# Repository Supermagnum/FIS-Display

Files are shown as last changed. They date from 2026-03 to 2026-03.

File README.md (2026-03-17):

# FIS-Display
VW Passat B6 FIS/MFA Display — Hardware Connections and Software Protocols.

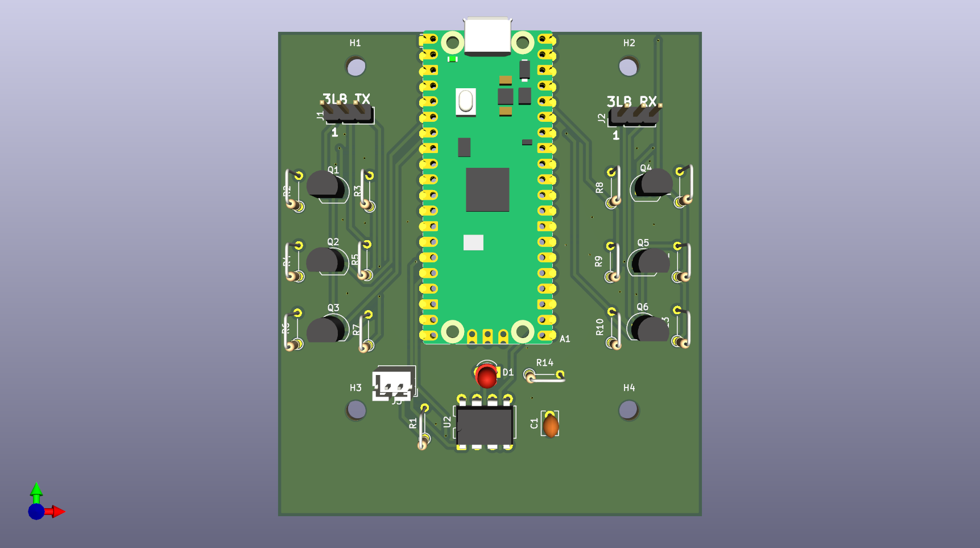
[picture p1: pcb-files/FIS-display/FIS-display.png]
FIS Display PCB (3D)


## Table of contents

- [Disclaimer](#disclaimer)
- [What this project does](#what-this-project-does)
- [Gerber files and PCB manufacturing](#gerber-files-and-pcb-manufacturing)
- [Project structure](#project-structure)
- [1. System Overview](#1-system-overview)
- [2. Host Device — Navit with D-Bus](#2-host-device--navit-with-d-bus)
  - [2.1 Supported Platforms](#21-supported-platforms)
  - [2.2 D-Bus Service Details](#22-d-bus-service-details)
  - [2.3 Key Attributes to Subscribe To](#23-key-attributes-to-subscribe-to)
  - [2.4 Navigation Status Values](#24-navigation-status-values)
  - [2.5 D-Bus Listener to Pico Bridge Script](#25-d-bus-listener--pico-bridge-script)
- [3. Serial Protocol (Host to Pico, 115200 baud)](#3-serial-protocol-host--pico-115200-baud-newline-terminated-ascii)
  - [3.1 Eco mode icon (driver-break, D-Bus)](#31-eco-mode-icon-driver-break-d-bus)
- [4. Transport — USB CDC or Bluetooth SPP](#4-transport--usb-cdc-or-bluetooth-spp)
  - [USB CDC](#usb-cdc)
  - [Bluetooth SPP](#bluetooth-spp)
- [5. Hardware](#5-hardware)
  - [5.1 Controller — Raspberry Pi Pico 2 W](#51-controller--raspberry-pi-pico-2-w)
  - [5.2 The 3LB (Three-Line Bus)](#52-the-3lb-three-line-bus)
  - [5.3 Level Shifting](#53-level-shifting)
  - [5.4 Instrument Cluster Connector (Green T32a)](#54-instrument-cluster-connector-green-t32a)
  - [5.5 3LB connection: pigtails or wire-to-wire (Molex kit)](#55-3lb-connection-pigtails-or-wire-to-wire-molex-kit)
  - [5.6 Pico 2 W GPIO Pinout](#56-pico-2-w-gpio-pinout)
  - [5.7 Cluster Coding Prerequisite](#57-cluster-coding-prerequisite)
- [6. The 3LB Protocol](#6-the-3lb-protocol)
  - [6.1 Open Source Libraries (Reference)](#61-open-source-libraries-reference)
  - [6.2 Display](#62-display)
  - [6.3 OEM radio: CAN time and display (reference only)](#63-oem-radio-can-time-and-display-reference-only)
  - [6.4 Other potentially useful CAN messages (reference only)](#64-other-potentially-useful-can-messages-reference-only)
- [7. Firmware Runtime Behaviour](#7-firmware-runtime-behaviour)
- [8. Software Stack Summary](#8-software-stack-summary)
- [9. Key References](#9-key-references)
- [10. Possible screen upgrade](#10-possible-screen-upgrade)

---
## Disclaimer

> The creator takes no responsibility for damages, immobile car, injury, or any other loss arising from the use of this project, its firmware, PCB design, or documentation. Use at your own risk.

## What this project does

[Navit](https://github.com/navit-gps/navit) is an open-source, modular turn-by-turn navigation engine that can run on Linux, Android, and other platforms. This project uses Navit on a host device (with D-Bus enabled) to drive the car's FIS/MFA display.

This repository provides firmware, PCB design, and documentation to show Navit navigation (and optionally media, call, clock) on the VW Passat B6 (3C) FIS/MFA display. 

A host device runs Navit with D-Bus and sends a simple serial protocol to a Raspberry Pi Pico 2 W over USB or Bluetooth (pair once as FIS-Bridge). 
The Pico injects frames onto the car's 3LB bus during idle gaps so the cluster shows turn-by-turn directions, street name, distance, and maneuver icons; when not navigating, it can show media track info, incoming call caller ID, or a clock screen with GPS time, ETA (e.g. ARR 14:32), remaining distance, and compass heading. 

The firmware supports CAN bus (MCP2561 on GPIO 11/12, 100 kbit/s, software CAN 2.0A send/receive); it is disabled by default and can be enabled with CFG:CAN:1. The Pico is a middleman only; all navigation logic stays on the host. When CAN bus is enabled, it can adjust your clock automatically. 

A separate display-test firmware is provided for bench-testing the cluster without a Navit host.

PCB and schematic are designed in [KiCad](https://www.kicad.org/). Design files and Gerbers are in [pcb-files/](pcb-files/). See [Gerber files and PCB manufacturing](#gerber-files-and-pcb-manufacturing) for what they are and how to use them.

> **Note:** The firmware in `firmware/` is **experimental and untested on a real vehicle**. Validate on the bench before connecting to the car. See [firmware/README.md](firmware/README.md) for build and flash instructions; that file also explains how to install the Raspberry Pi Pico SDK if it is missing.

## Gerber files and PCB manufacturing

**What are Gerber files?** Gerber is the standard format used by PCB manufacturers to produce printed circuit boards. Each file describes one layer of the board (copper, solder mask, silkscreen, etc.) as vector graphics. The manufacturer combines these files to fabricate and assemble the PCB. This repository provides Gerbers exported from the KiCad project in [pcb-files/FIS-display/](pcb-files/FIS-display/).

**What is in this repo:** In [pcb-files/FIS-display/gerbers/](pcb-files/FIS-display/gerbers/) you will find:

- **Copper layers:** `F_Cu.gbr` (top copper), `B_Cu.gbr` (bottom copper)
- **Solder mask:** `F_Mask.gbr`, `B_Mask.gbr`
- **Silkscreen:** `F_Silkscreen.gbr`, `B_Silkscreen.gbr`
- **Solder paste (SMD stencil):** `F_Paste.gbr`, `B_Paste.gbr`
- **Board outline:** `Edge_Cuts.gbr`
- **Drill files:** `*.drl` (through-hole and non-plated drill data)

**How to use them:**

1. **Ordering PCBs:** Zip the contents of the `gerbers/` folder (all `.gbr` and `.drl` files, and the `.gbrjob` file if the manufacturer supports it) and upload the zip to a PCB fab (e.g. JLCPCB, PCBWay, OSH Park, or similar). Select the correct units (usually mm) and board thickness; the fab will use the Gerbers to produce the boards. Use the same BOM as in [firmware/BOM.md](firmware/BOM.md) for sourcing components.

2. **Viewing without KiCad:** You can inspect the layers with a Gerber viewer (e.g. [GerberView](https://www.gerber-viewer.com/), or the online viewer many fabs provide) to check traces, pads, and outline before ordering.

3. **Editing the design:** Open the KiCad project in [pcb-files/FIS-display/](pcb-files/FIS-display/) (`.kicad_pro`, `.kicad_sch`, `.kicad_pcb`) in [KiCad](https://www.kicad.org/). After any change, re-export Gerbers from KiCad (File → Plot, then generate drill files) and replace the files in `gerbers/` before ordering new boards.

---

## Project structure

This repository uses **no symlinks**; all paths are normal directories and files so that every system can clone and use it without symlink support.

| Item | Description |
|---|---|
| [firmware/](firmware/) | Main Pico 2 W firmware: 3LB RX/TX, serial protocol, nav/media/clock injection, graphics. |
| [firmware/README.md](firmware/README.md) | Build, flash, pinout, and firmware behaviour. |
| [firmware/BOM.md](firmware/BOM.md) | Bill of materials for the PCB. |
| [firmware-display-test/](firmware-display-test/) | Standalone display test firmware: cycles through all modes (nav text, icons, call, media, clock) every 4 seconds. |
| [firmware-display-test/README.md](firmware-display-test/README.md) | How to build and use the display test. |
| [nav-icons/](nav-icons/) | Navigation and status icon SVGs (sources for the bitmaps in `firmware/fis_nav_icons.h`). See [nav-icons/README.md](nav-icons/README.md) for adding new icons. |
| [tools/](tools/) | Build/convert helpers. [tools/svg_to_fis_icon.py](tools/svg_to_fis_icon.py) converts SVG to the 64x64 1-bit C array format. [tools/navit_dbus_to_pico_bridge.py](tools/navit_dbus_to_pico_bridge.py) runs on the host and forwards Navit D-Bus (including eco_mode_fuel_enabled) to the Pico over serial. |
| [PQ35_46_ACAN_KMatrix_V5.20.6F_20160530_MH.xlsx](PQ35_46_ACAN_KMatrix_V5.20.6F_20160530_MH.xlsx) | VW/Audi PQ35/46 CAN matrix (reference). |
| [PQ35_46_ACAN_Glossary_DE_EN.md](PQ35_46_ACAN_Glossary_DE_EN.md) | German–English translation table for the CAN matrix document. |
| [pcb-files/](pcb-files/) | PCB design (KiCad) and [Gerber files](pcb-files/FIS-display/gerbers/) for manufacturing. See [Gerber files and PCB manufacturing](#gerber-files-and-pcb-manufacturing). |

---

## 1. System Overview

```
┌──────────────────────────────────────────────────────────┐
│  Host device running Navit with D-Bus enabled            │
│                                                          │
│  Examples:                                               │
│  • Android head unit (Navit built with D-Bus support)    │
│  • Linux carputer / Raspberry Pi running Navit           │
│  • Any platform where libbinding_dbus.so is active       │
│                                                          │
│  D-Bus listener translates Navit signals to serial       │
│  protocol and forwards to Pico over USB or Bluetooth     │
└────────────┬─────────────────────────┬───────────────────┘
             │                         │
     USB CDC serial            Bluetooth SPP
     /dev/ttyACM0              (onboard CYW43439)
     (also powers Pico)        "FIS-Bridge" PIN 0000
             │                         │
             └──────────┬──────────────┘
                        │
               ┌────────▼─────────┐
               │ Raspberry Pi     │
               │ Pico 2 W         │
               │ (RP2350)         │
               │                  │
               │ Middleman:       │
               │ serial -> 3LB;   │
               │ optional: GPIO   │
               │ 11/12 -> MCP2561 │
               └────────┬─────────┘
                        │
         ┌──────────────┼──────────────┐
         │              │              │
         ▼              │              ▼
 3LB (ENA/CLK/DATA)     │      Optional CAN (if enabled):
 via BS170 level        │      GPIO 11 (TX), 12 (RX) ->
 shifters (3.3V<->5V)   │      MCP2561 (TXD/RXD) -> CAN-H/CAN-L
         │              │              │
         ▼              │              ▼
 ┌──────────────────┐   │   ┌──────────────────────────┐
 │ VW Passat B6 (3C) │   │   │ Komfort-CAN (K-CAN)      │
 │ FIS/MFA cluster   │◄──┘   │ 100 kbit/s (when fitted) │
 │ 64x88 px, 1-bit   │       └──────────────────────────┘
 └────────┬──────────┘
          │
          ▼
 ┌───────────────────────┐
 │ Original ECU          │
 │ (talks 3LB natively,  │
 │  Pico co-exists via   │
 │  ENA arbitration)     │
 └───────────────────────┘
```

The Pico 2 W is a **pure middleman**. It has no navigation intelligence — it only receives
the serial protocol from the host device and injects the translated frames onto the 3LB bus.

All navigation logic stays on the host device running Navit. Optionally, when CAN is enabled
(see [5.6 Pico 2 W GPIO Pinout](#56-pico-2-w-gpio-pinout)), the Pico can communicate with the
vehicle Komfort-CAN (Comfort CAN / K-CAN, 100 kbit/s) via GPIO 11/12 to the MCP2561 (TXD/RXD only).

The original ECU continues to talk to the FIS/MFA natively over 3LB at all times. The Pico co-exists on the bus using the ENA line for arbitration — no relay or analog switch is needed.

> **Note:** The OEM radio has been replaced with an aftermarket head unit. The head unit does
> **not** communicate over 3LB. Only the original ECU talks to the FIS/MFA natively over 3LB.

---

## 2. Host Device — Navit with D-Bus

### 2.1 Supported Platforms

Navit can be built with D-Bus support (`libbinding_dbus.so`) on multiple platforms:

| Platform | Notes |
|---|---|
| Android head unit | Navit built with D-Bus support. Android includes D-Bus (`android_external_dbus`) |
| Linux carputer | Native D-Bus session bus, full support |
| Raspberry Pi (Linux) | Native D-Bus session bus, full support |
| Any Linux-based system | Native D-Bus session bus, full support |

Enable D-Bus in `navit.xml`:
```xml
<plugin path="$NAVIT_LIBDIR/*/${NAVIT_LIBPREFIX}libbinding_dbus.so" active="yes"/>
```

### 2.2 D-Bus Service Details

| Item | Value |
|---|---|
| Service name | `org.navit_project.navit` |
| Bus type | Session bus |
| Main object | `/org/navit_project/navit/default_navit` |
| Route object | `/org/navit_project/navit/default_navit/default_route` |
| Vehicle object | `/org/navit_project/navit/default_navit/default_vehicle` |

### 2.3 Key Attributes to Subscribe To

| Attribute | Meaning |
|---|---|
| `navigation_next_turn` | Upcoming maneuver type |
| `navigation_distance_turn` | Metres to next turn |
| `navigation_street_name` | Next street name |
| `navigation_street_name_systematic` | Route number |
| `navigation_status` | Routing state |
| `position_speed` | Current speed |
| `eta` | Estimated arrival (Unix timestamp); sent as `NAV:ETA`, shown in local time on FIS clock line |
| `destination_length` | Remaining distance to destination (m); sent as `NAV:REMAIN`, shown on FIS clock line |
| `position_direction` | Heading in degrees (0-360); sent as `NAV:HEAD`, shown as compass (N, NE, E, ...) on FIS |
| `position_time_iso8601` | GPS time UTC, format `YYYY-MM-DDTHH:MM:SSZ` (for FIS clock) |
| `position_coord_geo` | GPS latitude/longitude (for timezone lookup; vehicle attribute) |

### 2.4 Navigation Status Values

| Value | Meaning |
|---|---|
| `no_route` | No active route |
| `no_destination` | No destination set |
| `position_wait` | Waiting for GPS |
| `calculating` | Initial calculation |
| `recalculating` | Rerouting |
| `routing` | Active guidance |

### 2.5 D-Bus Listener to Pico Bridge Script

A bridge script runs on the host device and forwards Navit D-Bus attributes to the Pico over USB CDC or Bluetooth SPP. This repo includes **`tools/navit_dbus_to_pico_bridge.py`**, which implements the protocol and **eco_mode_fuel_enabled** support (Driver Break plugin): when `get_attr("eco_mode_fuel_enabled")` is true and a route has just been calculated (`navigation_status` = `routing`), it sends the eco icon for a short period (default 2.5 s), then the real first turn and distance so the FIS never shows eco instead of routing.

The driver-break plugin is awaiting merge and hardware testing; see [navit-gps/navit#1419](https://github.com/navit-gps/navit/pull/1419).

**Run (host):**
```bash
python3 tools/navit_dbus_to_pico_bridge.py --port /dev/ttyACM0   # USB CDC
python3 tools/navit_dbus_to_pico_bridge.py --port /dev/rfcomm0 --eco-seconds 2.5   # Bluetooth SPP
```

**Requirements:** Python 3, `pyserial`, PyGObject (`gi.repository.GLib`), `dbus`. Optional: Driver Break plugin in Navit for `eco_mode_fuel_enabled` (OBD-II / J1939 / MegaSquirt or adaptive fuel learning).

**Inline example (minimal, no eco logic)** for reference:

```python
#!/usr/bin/env python3
"""
Navit D-Bus listener -> Pico 2 W serial bridge.
Runs on any platform where Navit is built with libbinding_dbus.so active:
Android (with D-Bus support), Linux carputer, Raspberry Pi, etc.
Transport: USB CDC or Bluetooth SPP -- configure SERIAL_PORT below.
"""

import serial
import dbus
import dbus.mainloop.glib
from gi.repository import GLib

SERIAL_PORT = "/dev/ttyACM0"   # USB CDC, or e.g. /dev/rfcomm0 for Bluetooth SPP
BAUD = 115200

WATCHED = [
    "navigation_next_turn",
    "navigation_distance_turn",
    "navigation_street_name",
    "navigation_status",
    "eta",
    "destination_length",      # remaining distance (m) -> NAV:REMAIN, shown on FIS clock line
    "position_direction",      # heading 0-360 -> NAV:HEAD, shown as compass (N, NE, E, ...)
    "position_time_iso8601",   # UTC GPS time for FIS clock (format YYYY-MM-DDTHH:MM:SSZ)
    "position_coord_geo",      # lat/lon for timezone lookup (vehicle attribute)
]

MANEUVER_MAP = {
    "straight":          "straight",
    "turn_left":         "turn_left",
    "turn_right":        "turn_right",
    "turn_slight_left":  "slight_left",
    "turn_slight_right": "slight_right",
    "turn_sharp_left":   "sharp_left",
    "turn_sharp_right":  "sharp_right",
    "u_turn":            "u_turn",
    "keep_left":         "keep_left",
    "keep_right":        "keep_right",
    "destination":       "destination",
}

class NavitBridge:
    def __init__(self):
        self.ser = serial.Serial(SERIAL_PORT, BAUD, timeout=1)
        dbus.mainloop.glib.DBusGMainLoop(set_as_default=True)
        bus = dbus.SessionBus()
        obj = bus.get_object("org.navit_project.navit",
                             "/org/navit_project/navit/default_navit")
        iface = dbus.Interface(obj, dbus_interface="org.navit_project.navit")
        cb_path = iface.callback_attr_new()
        for attr in WATCHED:
            iface.add_attr(cb_path, attr)
        bus.add_signal_receiver(
            self.on_update,
            signal_name="callback_attr_update",
            dbus_interface="org.navit_project.navit",
            path=cb_path,
        )

    def on_update(self, attr_name, value):
        msg = None
        if attr_name == "navigation_next_turn":
            code = MANEUVER_MAP.get(str(value), str(value))
            msg = f"NAV:TURN:{code}\n"
        elif attr_name == "navigation_distance_turn":
            msg = f"NAV:DIST:{int(value)}\n"
        elif attr_name == "navigation_street_name":
            msg = f"NAV:STREET:{str(value)[:20]}\n"
        elif attr_name == "navigation_status":
            msg = f"NAV:STATUS:{str(value)}\n"
        elif attr_name == "eta":
            msg = f"NAV:ETA:{int(value)}\n"
        elif attr_name == "destination_length":
            msg = f"NAV:REMAIN:{int(value)}\n"
        elif attr_name == "position_direction":
            msg = f"NAV:HEAD:{int(value)}\n"
        elif attr_name == "position_time_iso8601":
            msg = f"NAV:TIME:{str(value)}\n"
        elif attr_name == "position_coord_geo":
            # value is typically (lng, lat) or struct; adapt to your D-Bus binding
            try:
                lat, lon = float(value[1]), float(value[0])  # (lng, lat) from Navit
                msg = f"NAV:POS:{lat:.4f},{lon:.4f}\n"
            except (IndexError, TypeError, ValueError):
                pass
        if msg:
            self.ser.write(msg.encode())

    def run(self):
        GLib.MainLoop().run()

if __name__ == "__main__":
    NavitBridge().run()
```

For full behaviour including eco icon when `eco_mode_fuel_enabled` is true, use **`tools/navit_dbus_to_pico_bridge.py`** (see above).

---

## 3. Serial Protocol (Host → Pico, 115200 baud, newline-terminated ASCII)

The same protocol is used regardless of whether the transport is USB CDC or Bluetooth SPP.

| Message | Meaning |
|---|---|
| `NAV:TURN:<code>` | Upcoming maneuver type. For eco icon (driver-break) see [3.1 Eco mode icon](#31-eco-mode-icon-driver-break-d-bus): use `eco_mode` or `eco` only when `eco_mode_fuel_enabled` is true and route is ready (see 3.1); it must **not** override routing instructions. |
| `NAV:DIST:<metres>` | Distance to next turn |
| `NAV:STREET:<n>` | Next street name (max 20 chars) |
| `NAV:STATUS:<status>` | Navit routing status |
| `NAV:ETA:<unix_ts>` | Estimated arrival (Unix timestamp); converted to local time and shown on clock line 2 as e.g. ARR14:32 |
| `NAV:REMAIN:<metres>` | Remaining distance to destination (from Navit `destination_length`); shown on clock line |
| `NAV:HEAD:<degrees>` | Heading 0-360 (from Navit `position_direction`); shown as compass on clock line |
| `NAV:TIME:<iso8601>` | GPS time UTC, e.g. `2026-03-14T12:34:56Z` (from Navit `position_time_iso8601`) |
| `NAV:POS:<lat>,<lon>` | GPS position in decimal degrees (from Navit `position_coord_geo`), e.g. `59.91,10.75` |
| `BT:TRACK:<info>` | Media track info from head unit |
| `BT:CALL:<caller>` | Incoming call caller ID |
| `BT:CALLEND` | Call ended |

### 3.1 Eco mode icon (driver-break, D-Bus)

The **eco mode** icon on the FIS is intended for the [Driver Break plugin](https://github.com/Supermagnum/navit/blob/feature/driver-break/docs/user/plugins/driver-break/index.rst) when fuel/energy is used in routing (ECU or adaptive fuel data). It must **never override routing instructions**: the host must only show the eco icon when appropriate and only for a short moment (e.g. after route planning finishes, before the first maneuver is displayed).

**Driver-break D-Bus attribute: `eco_mode_fuel_enabled`**

The plugin exposes a boolean attribute **eco_mode_fuel_enabled** on the Navit D-Bus interface. It is **true** when either (1) an ECU backend is available and running (OBD-II, J1939, or MegaSquirt), or (2) adaptive fuel learning is enabled in the plugin configuration. When **false**, no live ECU data and no adaptive learning are in use (energy-based routing may still be available without fuel data). See the [Driver Break D-Bus API (eco_mode_fuel_enabled)](https://github.com/Supermagnum/navit/blob/feature/driver-break/docs/user/plugins/driver-break/dbus.rst) for service, object path, interface, and examples in Python and `dbus-send`.

- **Service:** `org.navit_project.navit`
- **Method:** `get_attr("eco_mode_fuel_enabled")` on the navit object; returns `(attrname, value)` with a D-Bus boolean.

**When to show the eco icon**

- **`eco_mode_fuel_enabled` is true** (ECU running or adaptive fuel learning enabled).
- **Navit has planned or finished planning** a route that uses energy-based routing (fuel cost in the cost function).
- **Do not show eco when there is an active maneuver to display.** Example flow: when Navit finishes calculating a route and the above conditions are true, show the eco icon for a short period (e.g. 2–3 seconds), then send the actual first turn (`navigation_next_turn`) and distance so the FIS switches to normal turn-by-turn. The eco icon is an informational "route was planned with eco/fuel" hint, not a substitute for maneuver icons.

**Bridge script logic**

1. **Read the attribute** (e.g. on a timer or when `navigation_status` changes): call `get_attr("eco_mode_fuel_enabled")` on the navit object (see [dbus.rst](https://github.com/Supermagnum/navit/blob/feature/driver-break/docs/user/plugins/driver-break/dbus.rst) for object path and Python/dbus-send examples).
2. **Policy:** Send `NAV:TURN:eco_mode` to the Pico only when:
   - `eco_mode_fuel_enabled` is true, and
   - Route planning has just completed (e.g. `navigation_status` went to `routing`) or the route is ready and you are about to send the first maneuver.
3. Send `NAV:TURN:eco_mode` for a **short fixed duration** (e.g. 2–3 seconds), then immediately send the real first turn and distance (`NAV:TURN:<code>`, `NAV:DIST:<m>`) so the FIS shows the actual routing instruction. Never send or keep sending `eco_mode` when the user should see a turn icon (left, right, etc.).

The driver-break plugin is awaiting merge into the official Navit repo and hardware testing. See: https://github.com/navit-gps/navit/pull/1419

**Firmware behaviour:** The Pico displays whatever `NAV:TURN` code the host last sent. The **host is responsible** for never letting eco_mode override a maneuver: the bridge must only send `NAV:TURN:eco_mode` in the narrow window described above and then replace it with the real maneuver.

**Summary:** Eco icon = show only when `eco_mode_fuel_enabled` is true and route planning has just finished; display it briefly, then always switch to the real first (and subsequent) routing instructions.

**Feature toggles (clock screen):** Send `CFG:<name>:0` or `CFG:<name>:1` to enable or disable what is shown. Clock/ETA/compass/remain default to 1 (on). CAN bus has **full firmware support** (send/receive, 100 kbit/s, MCP2561) but is **disabled by default** (0).

| Message | Effect |
|---|---|
| `CFG:CLOCK:0` / `CFG:CLOCK:1` | Clock (time from GPS, set automatically); 0 = do not show clock on FIS |
| `CFG:ETA:0` / `CFG:ETA:1` | ETA in local time on clock line 2 (e.g. ARR14:32) |
| `CFG:COMPASS:0` / `CFG:COMPASS:1` | Compass heading (N, NE, ...) on clock line 2 |
| `CFG:REMAIN:0` / `CFG:REMAIN:1` | Remaining distance on clock line 2 |
| `CFG:CAN:0` / `CFG:CAN:1` | CAN bus (full support: send/receive at 100 kbit/s, **disabled by default**). Enable with 1 when MCP2561 is connected to GPIO 11/12. |

---

## 4. Transport — USB CDC or Bluetooth SPP

The host device can connect to the Pico over either transport. The Pico listens on both
USB CDC and Bluetooth SPP simultaneously.

### USB CDC
- Connect a USB cable from the host to the Pico USB port
- Pico appears as `/dev/ttyACM0` (Linux) or equivalent on Android
- **Also provides 5 V power to the Pico via VSYS** — no separate power supply needed
- Baud rate: 115200

### Bluetooth SPP
- Pico advertises as `FIS-Bridge` using classic Bluetooth SPP via BTstack (onboard CYW43439)
- No external Bluetooth module required
- **Pair once:** scan for `FIS-Bridge`, enter PIN `0000` if prompted — reconnects automatically
- On Linux: Pico appears as `/dev/rfcomm0` after pairing
- Baud rate: 115200

> If using Bluetooth only (no USB), the Pico needs a separate 5 V power source via the VSYS
> pin — e.g. a car USB adapter or a 12 V → 5 V regulator on the PCB.

---

## 5. Hardware

### 5.1 Controller — Raspberry Pi Pico 2 W

| Property | Value |
|---|---|
| MCU | RP2350 (dual-core Cortex-M33, 150 MHz) |
| RAM | 520 KB SRAM |
| Flash | 4 MB |
| Wireless | Infineon CYW43439 — WiFi + classic Bluetooth |
| Logic level | 3.3 V GPIO |
| Power | 5 V via VSYS (USB or external) |
| DigiKey P/N | SC0919 |

### 5.2 The 3LB (Three-Line Bus)

| Wire | Function | Direction |
|---|---|---|
| ENA | Enable / bus arbitration | Bidirectional |
| DATA | Serial data | Master → Cluster |
| CLK | Clock | Master → Cluster |

Bus runs at **5 V logic**. The 3LB clock speed is **suspected to be ~125–130 kHz** (transmission/bit rate). The actual documented value is difficult to find; the BAP FCNav function catalogue does not specify the physical layer, and other sources sometimes quote conflicting numbers (e.g. 2300 Hz or 2300 kHz). The firmware is configured for ~125 kHz by default; see below for how to measure the speed on your bus and adjust the code. Pico GPIO is 3.3 V — level shifting required on all lines.

**Bus arbitration:** Before transmitting, a master pulls ENA low to claim the bus. If ENA is already
low (another device is transmitting), it waits. The cluster acknowledges with a 100 µs pulse (e.g. ENA high). The Pico and ECU safely share the bus without any relay or switch.

**Measuring 3LB clock speed and adjusting the firmware:** To confirm or correct the bus speed on your cluster:

1. **Measure the CLK line** with an oscilloscope or logic analyzer while the OEM radio or nav unit is transmitting to the cluster (or while the Pico is transmitting). Measure the frequency of the CLK signal during an active frame (ENA low). One full clock period = one bit; the frequency in Hz is the bit rate.
2. **If your measured frequency differs from ~125 kHz**, edit the firmware to match. In `firmware/fis_display.c`, change the constant `FIS_3LB_TX_CLK_HZ` (default 125000) to your measured value in Hz. Rebuild and flash. Example: if you measure 130 kHz, set `#define FIS_3LB_TX_CLK_HZ 130000u`.
3. **Optional:** If you have a different PIO program with a different number of cycles per bit, adjust `FIS_3LB_TX_CYCLES_PER_BIT` (default 6) to match so the divider calculation stays correct.

### 5.3 Level Shifting

6× **BS170** N-channel MOSFET (TO-92, through-hole), one per 3LB GPIO line (3 RX + 3 TX).
Each channel uses two 2.2 kΩ pull-up resistors — one to 3.3 V, one to 5 V. Use non-inductive resistors (e.g. metal film or SMD thick/thin film); avoid wirewound types.

| Part | DigiKey P/N | Qty |
|---|---|-----|
| BS170 MOSFET TO-92 THT | BS170-ND | 6 |
| 2.2 kΩ resistor 0.25 W THT (non-inductive) | — | 12 |

BS170 pinout (flat face toward you, left to right): **Source — Gate — Drain**.

### 5.4 Instrument Cluster Connector (Green T32a)

| T32a Pin | Signal |
|---|---|
| 30 | DATA |
| 31 | CLK |
| 32 | ENA |

Connector type: Kostal MLK 1.2 / MQS 0.63 mm. Use a VAG pin tool to back-probe terminals.
Do not cut harness wires unless you are absolutely sure what you are doing.
One option is to cut the harness wires needed and add connectors so you can plug the PCB in line; then you can unplug both sides and connect them directly to bypass the board for repairs or to restore original function. Use the Molex 3-circuit kit (see below) for pigtails from the PCB or for a pure wire-to-wire connection.

### 5.5 3LB connection: pigtails or wire-to-wire (Molex kit)

No PCB-mounted connector. Use one **Molex 3-circuit connector kit** (DigiKey **23-0766500064-ND**, Molex **0766500064**, "KIT CONN STD .062" 3 CIRCUITS"). The kit is the complete solution for both PCB pigtails and wire-to-wire.

**With PCB (pigtails):** Solder two short pigtail wires directly to the PCB RX and TX pad areas. On the free end of each pigtail, crimp the correct connector from the kit:

| Side | PCB pad | Free end (from kit) |
|---|---|---|
| **RX** | Solder wire to PCB RX pads | Female receptacle housing **0003061038** with socket terminals **0002061103** |
| **TX** | Solder wire to PCB TX pads | Plug housing **0003062033** with pin terminals **0002062103** |

Incoming field cables then plug into those pigtails — female into male, male into female. The different housing genders prevent swapping RX and TX.

**Wire-to-wire (no PCB):** To connect two cables with no board in between, plug the kit female receptacle housing directly into the male plug housing. No PCB, no soldering, no extra parts.

| Part | DigiKey P/N | Qty |
|---|---|-----|
| Molex 3-circuit connector kit (.062" / 1.57 mm) | 23-0766500064-ND | 1 |

### 5.6 Pico 2 W GPIO Pinout

**3LB RX — monitor ECU frames, detect bus idle (inputs, via level shifter):**

| GPIO | Signal |
|---|---|
| GPIO0 | FIS_PIN_ENA — monitors bus idle state |
| GPIO1 | FIS_PIN_CLK — input to PIO SM0 |
| GPIO2 | FIS_PIN_DATA — input to PIO SM0 |

**3LB TX — inject frames during idle gaps (outputs, via level shifter):**

| GPIO | Signal |
|---|---|
| GPIO3 | FIS_PIN_ENA_OUT — claims bus before injecting |
| GPIO4 | FIS_PIN_CLK_OUT — PIO SM1 side-set |
| GPIO5 | FIS_PIN_DATA_OUT — PIO SM1 out_base |

**Optional CAN (firmware supports full CAN; when enabled, MCP2561):** On the VW Passat B6 (PQ46 platform) the bus connecting the instrument cluster to the rest of the modules is the **Komfort-CAN** (Comfort CAN), also referred to as **K-CAN** or **KCAN**. The CAN transceiver used is the MCP2561. It has only 2 signal connections: TXD and RXD. 3.3 V logic; no level shifter needed. See `firmware/fis_can.h` and firmware README.

| GPIO | Signal | Direction | Notes |
|---|---|---|---|
| GPIO11 | FIS_CAN_PIN_TX | Out | TX CAN to MCP2561 TXD |
| GPIO12 | FIS_CAN_PIN_RX | In | RX CAN from MCP2561 RXD |

MCP2561 CANH/CANL connect to the vehicle Komfort-CAN (Comfort CAN / K-CAN, 100 kbit/s). For when to add a 120 ohm termination (tapped in middle vs replacing radio vs bench), see firmware README.

**PQ46 CAN buses:** The Komfort-CAN is distinct from the other two CAN buses on the platform:

| Bus | Bit rate | Typical traffic |
|-----|---|---|
| **Komfort-CAN** (K-CAN) | 100 kbit/s | Instrument cluster, convenience modules, gateway; messages like mKombi_1, mDiagnose_1 |
| **Antriebs-CAN** (ACAN / Drivetrain CAN) | 500 kbit/s | Engine, ABS, airbag, gearbox |
| **Infotainment-CAN** (ICAN) | 100 kbit/s | Radio, navigation, phone module |

The **CAN gateway (J533)** sits between these buses and bridges messages as needed. When your Pico (via MCP2561) taps into the bus to read or send messages such as mKombi_1, mDiagnose_1, etc., it is connecting to the **Komfort-CAN** (K-CAN), not to ACAN or ICAN.

### 5.7 Cluster Coding Prerequisite

Code the cluster using **VCDS** or **OBDeleven**, Module **17 — Instruments**:
enable **"Navigation present"**. Without this the navigation slot in the FIS/MFA is inactive
even if the Pico sends correct 3LB frames.

---

## 6. The 3LB Protocol

### 6.1 Open Source Libraries (Reference)

| Library | URL | Notes |
|---|-----|---|
| TLBFISLib | https://github.com/domnulvlad/TLBFISLib | Most complete, actively maintained |
| VAGFISWriter | https://github.com/tomaskovacik/VAGFISWriter | Original reverse-engineered implementation |
| FISCuntrol | https://github.com/adamforbes92/FISCuntrol | Complete project, author uses in own car |
| FISBlocks | https://github.com/ibanezgomez/FISBlocks | 3LB + KWP1281 OBD combined |

The Pico firmware reimplements 3LB directly in PIO state machines timed to the BAP FCNav
SDP30DF48V280F specification — no Arduino library dependency.

### 6.2 Display

The FIS/MFA (Fahrerinformationssystem / Multifunktionsanzeige) screen is a **64×88 pixel
monochrome LCD**, 1-bit. Navigation maneuver icons are pre-generated 64×64 px 1-bit arrays
stored in flash (`firmware/fis_nav_icons.h`) and rendered with:
```c
GraphicFromArray(x, y, width, height, array, 0); // 0 = flash/PROGMEM
```

### 6.3 OEM radio: CAN time and display (reference only)

The **original VW radio** set the instrument cluster time via the **CAN bus** (CAN-H / CAN-L), using time it received from the **FM RDS network**. This project does **not** use CAN for the clock; the Pico sets the FIS clock from GPS (Navit) over serial and 3LB only. The following is documented for reference.

**OEM messages implemented:** When CAN is enabled (`CFG:CAN:1`), the firmware sends **mDiagnose_1** (0x7D0) with local date/time derived from GPS (NAV:TIME + position for timezone) every 1000 ms, and **mEinheiten** (0x60E) with display format (24 h, EU date, units). The cluster can use mDiagnose_1 to set its internal clock. The FIS clock display is still driven by the serial protocol and 3LB injection; mDiagnose_1 allows the cluster’s own time display to stay in sync when CAN is connected.

| Message | CAN ID | Length | Period | Description |
|---|---|---|---|---|
| **mDiagnose_1** | 0x7D0 (2000) | 8 bytes | 1000 ms | Date and time from radio (e.g. RDS). |
| **mEinheiten** | 0x60E (1550) | 2 bytes | 1000 ms | Display format flags (date/clock on-off, day of week). |

**mDiagnose_1 (0x7D0) — date and time**

| Signal | Byte | Start bit | Length | Range | Unit |
|---|---|---|---|---|---|
| DI1_Jahr (Year) | 4 | 4 | 7 bits | 0–127 → 2000–2127 | Year |
| DI1_Monat (Month) | 5 | 3 | 4 bits | 1–12 | Month |
| DI1_Tag (Day) | 5 | 7 | 5 bits | 0–31 | Day |
| DI1_Stunde (Hour) | 6 | 4 | 5 bits | 0–23 | Hours |
| DI1_Minute (Minute) | 7 | 1 | 6 bits | 0–59 | Minutes |
| DI1_Sekunde (Second) | 7 | 7 | 6 bits | 0–59 | Seconds |
| DI1_Zeit_alt (time stale) | 8 | 7 | 1 bit | — | 1 = time old/stale |

Sent cyclically every 1000 ms.

**mEinheiten (0x60E) — display format**

| Signal | Byte | Bit(s) | Description |
|---|---|---|---|
| EH1_Datum_Anzeige | 1 | 6 | Date display on/off |
| EH1_Uhr_Anzeige | 1 | 7 | Clock display on/off |
| EH1_Wochentag | 2 | 4–6 | Day of week |

Sent cyclically every 1000 ms.

### 6.4 Other potentially useful CAN messages (reference only)

**mDiagnose_1** and **mEinheiten** are implemented and sent when CAN is enabled (see 6.3). The following CAN frames are not yet implemented; they are documented for reference. You can add handling for these or other IDs using `fis_can_send()` / `fis_can_receive()`.

**Useful for FIS/display**

- **mKombi_1 (0x320)** — sent by the cluster, 10 ms cyclic: KO1_kmh (vehicle speed, bytes 4–5, 15 bits), KO1_angez_kmh (displayed speed including offset, bytes 6–7), KO1_Tankinhalt (fuel level), KO1_Warn_Tank (low fuel, 7 L), KO1_Oeldruck (oil pressure warning), KO1_Kuehlmittel (coolant warning), KO1_Vorgluehen (glow plug, diesel).
- **mKombi_2 (0x420)** — from cluster, 200 ms cyclic: KO2_gef_Auss_T / KO2_Aussen_T (outside temperature), KO2_Bel_Displ (display brightness %, for dimming FIS at night), KO2_Fehlereintr (fault stored).
- **mEinheiten (0x60E)** — units: EH1_Uhr_Anzeige (12h/24h), EH1_Datum_Anzeige (EU/US date), EH1_Wochentag (day of week 1=Mon…7=Sun), EH1_Einh_Temp (°C/°F), EH1_Einh_Strck (km/miles).

**Situational awareness**

- **mGate_Komf_1 (0x390)**, 100 ms: GK1_Rueckfahr (reverse), GK1_Warnblk_Status (hazards), GK1_Bremslicht, GK1_Abblendlicht / GK1_Fernlicht (headlights/high beam), GK1_Wischer_vorn (wipers), GK1_SH_laeuft (aux heater), door status (driver, passenger, rear L/R).
- **mZAS_1 (0x572)** — ignition: ZA1_Klemme_15 (ignition on), ZA1_Klemme_50 (starter), ZA1_S_Kontakt (key in).
- **mClima_1 (0x5E0)** — CL1_Kompressor (A/C on), CL1_Hecksch / CL1_Frontsch (rear/front screen heat), CL1_Restwaerme (residual heat).

**Parking (if equipped)**

- **Parkhilfe_01 (0x497)** — PDC: obstacle front/rear, beeper active, audio ducking request, system state.

**Other**

- **mKombi_3 (0x520)** — KO3_Kilometer (odometer), KO3_Standzeit (parked duration).
- **mSysteminfo_1 (0x5D0)** — SY1_Fzg_Derivat (body style), SY1_Notbrems_Status (emergency braking).

**Signal reference tables**

*mKombi_1 — 0x320 (from cluster, 10 ms cyclic)*

| Signal | Byte | Start bit | Len | Raw range | Physical | Unit | Scale |
|---|---|---|-----|---|---|---|---|
| KO1_kmh | 4 | 1 | 15 | 0–32600 | 0–326 | km/h | 0.01 |
| KO1_angez_kmh | 6 | 6 | 10 | 0–1018 | 0–325.76 | km/h | 0.32 |
| KO1_Tankinhalt | 3 | 0 | 7 | 0–126 | 0–126 | litres | 1 |
| KO1_Warn_Tank | 1 | 6 | 1 | — | 1 = warning (7 L) | — | — |
| KO1_Oeldruck | 1 | 2 | 1 | — | 1 = low pressure | — | — |
| KO1_Kuehlmittel | 1 | 4 | 1 | — | 1 = coolant low | — | — |
| KO1_Vorgluehen | 1 | 7 | 1 | — | 1 = glow plug on | — | — |

KO1_angez_kmh spans bytes 6–7 (10 bits from bit 6); KO1_kmh spans bytes 4–5 (15 bits from bit 1). Little-endian.

*mKombi_2 — 0x420 (from cluster, 200 ms cyclic)*

| Signal | Byte | Start bit | Len | Raw range | Physical | Unit | Offset | Scale |
|---|---|---|-----|---|---|---|---|---|
| KO2_gef_Auss_T | 2 | 0 | 8 | 0–254 | −50 to +77 | °C | −50 | 0.5 |
| KO2_Aussen_T | 3 | 0 | 8 | 0–254 | −50 to +77 | °C | −50 | 0.5 |
| KO2_Bel_Displ | 6 | 0 | 7 | 0–100 | 0–100 | % | 0 | 1 |
| KO2_Fehlereintr | 1 | 7 | 1 | — | 1 = fault stored | — | — | — |

Temperature: °C = (raw × 0.5) − 50. Raw 0xFF = invalid.

*mEinheiten — 0x60E (1000 ms cyclic)*

| Signal | Byte | Start bit | Len | Values |
|---|---|---|-----|---|
| EH1_Uhr_Anzeige | 1 | 7 | 1 | 0 = 24 h, 1 = 12 h |
| EH1_Datum_Anzeige | 1 | 6 | 1 | 0 = EU (DD.MM), 1 = US (MM/DD) |
| EH1_Wochentag | 2 | 4 | 3 | 0 = init, 1 = Mon … 7 = Sun |
| EH1_Einh_Temp | 1 | 1 | 1 | 0 = °C, 1 = °F |
| EH1_Einh_Strck | 1 | 0 | 1 | 0 = km, 1 = miles |

*mGate_Komf_1 — 0x390 (100 ms cyclic)*

| Signal | Byte | Start bit | Len | Notes |
|---|---|---|-----|---|
| GK1_Rueckfahr | 4 | 4 | 1 | 1 = reverse |
| GK1_Warnblk_Status | 7 | 7 | 1 | 1 = hazards on |
| GK1_Bremslicht | 8 | 3 | 1 | 1 = brake light on |
| GK1_Abblendlicht | 7 | 0 | 1 | 1 = dipped beam |
| GK1_Fernlicht | 7 | 1 | 1 | 1 = high beam |
| GK1_Wischer_vorn | 7 | 2 | 1 | 1 = wipers moving |
| GK1_SH_laeuft | 8 | 0 | 1 | 1 = aux heater on |
| GK1_Fa_Tuerkont | 3 | 0 | 1 | Driver door |
| BSK_BT_geoeffnet | 6 | 1 | 1 | Passenger door |
| BSK_HL_geoeffnet | 4 | 2 | 1 | Rear left door |
| BSK_HR_geoeffnet | 4 | 3 | 1 | Rear right door |

*mZAS_1 — 0x572 (ignition/key)*

| Signal | Byte | Start bit | Len | Notes |
|---|---|---|-----|---|
| ZA1_S_Kontakt | 1 | 0 | 1 | 1 = key inserted |
| ZA1_Klemme_15 | 1 | 1 | 1 | 1 = ignition on |
| ZA1_Klemme_50 | 1 | 3 | 1 | 1 = starter engaged |

*mClima_1 — 0x5E0*

| Signal | Byte | Start bit | Len | Notes |
|---|---|---|-----|---|
| CL1_Kompressor | 1 | 4 | 1 | 1 = A/C on |
| CL1_Hecksch | 1 | 2 | 1 | 1 = rear screen heat |
| CL1_Frontsch | 1 | 3 | 1 | 1 = front screen heat |
| CL1_Restwaerme | 7 | 3 | 1 | 1 = residual heat on |

*Parkhilfe_01 — 0x497 (if equipped)*

| Signal | Byte | Start bit | Len | Notes |
|---|---|---|-----|---|
| PH_Opt_Anz_V_Hindernis | 3 | 2 | 1 | 1 = obstacle front |
| PH_Opt_Anz_H_Hindernis | 3 | 3 | 1 | 1 = obstacle rear |
| PH_Tongeber_V_aktiv | 3 | 4 | 1 | 1 = PDC beep front |
| PH_Tongeber_H_aktiv | 3 | 5 | 1 | 1 = PDC beep rear |
| PH_Anf_Audioabsenkung | 3 | 7 | 1 | 1 = audio duck request |
| PH_Systemzustand | 8 | 2 | 3 | 0 = off, 1 = reverse, 2 = front, 3 = both, 7 = fault |

*mKombi_3 — 0x520*

| Signal | Byte | Start bit | Len | Raw range | Physical | Unit | Scale |
|---|---|---|-----|---|---|---|---|
| KO3_Kilometer | 6 | 0 | 20 | 0–1048575 | 0–1048575 | km | 1 |
| KO3_Standzeit | 4 | 0 | 15 | 0–32767 | 0–131068 | seconds | ×4 |

KO3_Standzeit = time since last ignition-off in 4-second steps (max ~36.4 h).

*mSysteminfo_1 — 0x5D0*

| Signal | Byte | Start bit | Len | Values |
|---|---|---|-----|---|
| SY1_Fzg_Derivat | 3 | 0 | 4 | 0 = saloon, 1 = notchback, 2 = estate, 3 = hatchback, 4 = coupé, 5 = cabriolet, 6 = offroad, 9 = other |
| SY1_Notbrems_Status | 8 | 0 | 1 | 1 = emergency braking |

---

## 7. Firmware Runtime Behaviour

**Core 0:**
- Initialises USB CDC and BTstack SPP (`FIS-Bridge`, PIN `0000`)
- Reads `NAV:*`, `BT:*`, and `CFG:*` messages from both interfaces non-blocking
- Updates shared `nav_state_t` and feature toggles (`fis_config_t`) under a critical section
- When CAN is enabled (`CFG:CAN:1`), runs CAN poll (firmware has full CAN support: send/receive at 100 kbit/s via MCP2561 on GPIO 11/12)

**Core 1:**
- Monitors 3LB ENA/CLK/DATA via PIO SM0 (RX sniffer)
- Detects idle gaps between ECU transmissions
- When bus is idle, checks `nav_state_t` and feature toggles (`fis_config_t`), then injects:
  - Active call → call frame (highest priority)
  - Active navigation (`routing` / `recalculating`) → nav icon + street name + distance
  - Media info present, no nav → track name frame
  - Clock enabled and GPS time available → clock frame (local time on line 1; line 2: remain / ETA / compass / date per toggles)
  - Otherwise → do nothing; ECU frames reach FIS/MFA unmodified

**Injection:** Wait ENA LOW (bus idle) → raise ENA → transmit via PIO SM1 → lower ENA → ECU resumes.

---

## 8. Software Stack Summary

| Layer | Technology | Where it runs |
|---|---|---|
| Navigation engine | Navit (with `libbinding_dbus.so`) | Host device (Android, Linux, etc.) |
| D-Bus listener + serial bridge | Python 3 (`dbus`, `pyserial`) | Host device |
| Serial transport | USB CDC or Bluetooth SPP | Host ↔ Pico |
| Bus monitor + arbitration | PIO SM0 (3LB RX) | Pico 2 W |
| FIS/MFA frame injector | PIO SM1 (3LB TX) | Pico 2 W |
| Bluetooth receiver | BTstack SPP (CYW43439) | Pico 2 W |
| FIS/MFA display | 3LB hardware (ENA/DATA/CLK) | Pico → Cluster |

---

## 9. Key References

| Resource | URL |
|---|-----|
| PQ35/46 CAN K-Matrix (VW/Audi) | https://github.com/Supermagnum/FIS-Display/blob/main/PQ35_46_ACAN_KMatrix_V5.20.6F_20160530_MH.xlsx |
| PQ35/46 CAN Glossary (DE–EN) | https://github.com/Supermagnum/FIS-Display/blob/main/PQ35_46_ACAN_Glossary_DE_EN.md |
| Navit D-Bus external dashboard spec | https://github.com/Supermagnum/navit/blob/feature/navit-dash/docs/development/navit_dbus_external_dashboards.rst |
| Navit driver-break plugin (index) | https://github.com/Supermagnum/navit/blob/feature/driver-break/docs/user/plugins/driver-break/index.rst |
| Navit driver-break D-Bus API (eco_mode_fuel_enabled) | https://github.com/Supermagnum/navit/blob/feature/driver-break/docs/user/plugins/driver-break/dbus.rst |
| Navit project | https://github.com/navit-gps/navit |
| TLBFISLib | https://github.com/domnulvlad/TLBFISLib |
| VAGFISWriter | https://github.com/tomaskovacik/VAGFISWriter |
| VAGFISReader theory of operation | https://github.com/tomaskovacik/VAGFISReader/wiki/Theory-of-operation |
| FISCuntrol | https://github.com/adamforbes92/FISCuntrol |
| FISBlocks | https://github.com/ibanezgomez/FISBlocks |
| FIS-Fool intercept concept | http://kuni.bplaced.net/_Homepage/FisFool/FisFool_Overview_e.html |
| BAP FCNav SDP30DF48V280F (3LB timing spec) | https://github.com/Supermagnum/FIS-Display/blob/main/pdfcoffee.com_bap-fcnav-sdp30df48v280fpdf-pdf-free.pdf |
| SVG maneuver icons | https://github.com/Supermagnum/navit/tree/feature/navit-dash/docs/development/svg-examples |
| Raspberry Pi Pico 2 W datasheet | https://datasheets.raspberrypi.com/picow/pico-2-w-datasheet.pdf |

## 10. Possible screen upgrade

Finding something that has a large enough active area and is compatible with the pico is not easy, so this is only used as a example:

A possible future upgrade from the stock 64x88 monochrome FIS to a colour TFT: **MSP3525** — 3.5" IPS SPI module, ST7796 (no touch).

**No firmware support for the updated screen or TFT icons is included in this repository** — the following is for implementers.

### Key specifications (MSP3525)

| Parameter | Value |
|---|---|
| Screen size | 3.5 inch |
| Panel type | IPS (full viewing angle) |
| Resolution | 320x480 pixels |
| Active area | 48.96 x 73.44 mm |
| TFT outline | 55.50 x 84.96 x 2.5 mm |
| PCB size (with header) | 55.5 x 98.0 x 12.98 mm |
| Driver IC | ST7796U |
| Interface | 4-wire SPI |
| Colors | 16.7M |
| Brightness | 300 cd/m² |
| Backlight | 6x white LED |
| Working voltage | 3.3 V or 5 V |
| Backlight current | 95 mA |
| Power | 0.5 W |
| Operating temp | -30 to +80 C |
| SD card slot | Micro TF |
| Connector | 14P 2.54 mm header + 14P 0.5 mm FPC |
| Weight | 73 g |

### 14-pin header pinout

| Pin | Label | Description |
|-----|---|---|
| 1 | VCC | Power (3.3 V or 5 V) |
| 2 | GND | Ground |
| 3 | LCD_CS | Chip select, active low |
| 4 | LCD_RST | Reset, active low |
| 5 | LCD_RS | Data/Command (high = data, low = command) |
| 6 | SDI (MOSI) | SPI data in (shared with SD) |
| 7 | SCK | SPI clock (shared with SD) |
| 8 | LED | Backlight PWM or 3.3 V for always-on |
| 9 | SDO (MISO) | SPI data out (shared with SD) |
| 10 | CTP_SCL | Touch I2C clock — not used on MSP3525 |
| 11 | CTP_RST | Touch reset — not used on MSP3525 |
| 12 | CTP_SDA | Touch I2C data — not used on MSP3525 |
| 13 | CTP_INT | Touch interrupt — not used on MSP3525 |
| 14 | SD_CS | SD card chip select, active low |

**Notes for this project:**
- Pins 10–13 are unpopulated on the MSP3525 (no touch hardware).
- MOSI, MISO and SCK are shared between LCD and SD card — only CS lines differ.
- LED pin connects to Pico PWM for KO2_Bel_Displ auto-dimming.
- SD_CS is a separate CS pin — SD card and display share SPI; use separate CS on the Pico.
- TFT_eSPI has RP2040 support.

**Icons:** Any updated screen + Pico firmware that implements the MSP3525 UI should use the icon artwork from the **nav-icons** folder (SVG sources; convert to the format your display driver needs). The existing `firmware/fis_nav_icons.h` bitmaps are 64x64 1-bit for the stock FIS; for a colour TFT you can derive icons from the same SVGs in nav-icons.

**If the screen is upgraded** to the MSP3525 (or similar TFT), the following do **not** need to be populated on the PCB: **R2–R7**, **Q1–Q3**, and wires soldered into **J1** (the 3LB level-shifter and connector parts are for driving the stock FIS only).

The connector is a standard **2.54 mm (0.1") pitch straight male pin header** (breadboard-compatible) that mates with any standard 2.54 mm female Dupont connector.

**Preferred Pico pins for the screen:** Use **GPIO 16 to 22** to interface the Raspberry Pi Pico to the MSP3525 (e.g. assign CS, RESET, DC, MOSI, SCK, and LED backlight PWM within this range in your display driver).

**Display driver (Pico C SDK):** This project uses the **Pico C SDK**, not Arduino. TFT_eSPI is Arduino-based and does not directly fit without an Arduino/Pico wrapper.

The [LCD wiki](https://www.lcdwiki.com/) provides official demo code for the MSP3218/MSP3222. Relevant downloads: [LCD wiki MSP3218 resources](https://www.lcdwiki.com/res/MSP3218/) — contains Arduino, C51 and STM32 examples. None of these are native Pico C SDK.

**Best options for this project (native Pico C SDK or plain C):**

| Option | URL | Notes |
|---|-----|---|
| Native Pico C SDK — ILI9341 | [rprouse/ILI9341_PICO_DisplayExample](https://github.com/rprouse/ILI9341_PICO_DisplayExample) | Already found; native Pico SDK, most directly usable |
| Clean C driver (easily ported to Pico) | [afiskon/stm32-ili9341](https://github.com/afiskon/stm32-ili9341) | Clean STM32 HAL C driver, well structured, plain C with SPI abstraction |
| Most complete C library | [martnak/STM32-ILI9341](https://github.com/martnak/STM32-ILI9341) | Full HAL driver with graphics primitives, text, bitmaps |

The rprouse Pico example combined with the afiskon or martnak graphics layer gives you everything needed — initialisation, drawing primitives, text, and bitmap rendering — all in plain C that maps cleanly to the Pico SDK's `hardware/spi.h`.

**Backlight:** Either drive the backlight always on, or use PWM from the Pico tied to **KO2_Bel_Displ** for auto-dimming. KO2_Bel_Displ is the display brightness signal from the cluster, sent on the K-CAN in message mKombi_2 (0x420).

### Window addressing and bezel fit

The ILI9341 has a built-in window addressing command — **SET_COLUMN_ADDRESS (0x2A)** and **SET_PAGE_ADDRESS (0x2B)** — which define a rectangular region of the display RAM to write to. Everything outside that window is untouched.

**Workflow:**

1. Measure the visible area through the bezel opening in pixels.
2. Calculate the offset from the display edges to the bezel opening.
3. Set the window to match. For example, if the bezel exposes a 200x280 area starting at x=20, y=20:

```c
// Set column window: x_start to x_end
ILI9341_SetAddressWindow(20, 20, 219, 299);

// Now all drawing commands only affect that region
// Pixels outside are never written
```

This means:
- No wasted SPI bandwidth writing pixels that are hidden
- No flickering at the bezel edge
- The display treats the window as its full canvas

**Practical approach:**
- Mount the display behind the bezel temporarily.
- Power it up with a full white screen.
- Measure through the opening which pixels are visible.
- Hardcode those as `#define DISPLAY_X_OFFSET`, `DISPLAY_Y_OFFSET`, `DISPLAY_WIDTH`, `DISPLAY_HEIGHT`.
- All drawing code uses those constants as the canvas bounds.

This is the standard approach used in all embedded TFT projects where the display is larger than the visible window.

The firmware parses K-CAN when CAN is enabled (`CFG:CAN:1`): see `firmware/fis_can_rx.c` and `fis_can_rx_state_t` in `firmware/fis_can_rx.h`. With a new screen fitted you can use the parsed state for graphics.

**With a new screen fitted you can do:**

**From K-CAN the Pico knows:**
- Vehicle speed – animated speedo needle or bar
- Outside temperature – with colour coding (blue to white to red)
- Fuel level – animated gauge
- Display brightness – auto-dim the TFT backlight
- Ignition state – wake/sleep animations
- Reverse gear – switch to a different screen layout
- Door status – animated car outline showing open doors
- Hazard lights – visual indicator
- Wipers active – rain animation
- PDC obstacles – animated proximity bars front/rear
- Coolant/oil warnings – animated warning icons
- Glow plug – animated diesel preheat indicator
- Standzeit – how long the car has been parked

**From 3LB RX the Pico knows:**
- Navigation turn instructions – animated arrow
- Street names
- Radio/media info

**From Navit D-Bus:**
- Turn-by-turn with distance – animated countdown bar
- ETA
- Current speed vs limit

A more viable solution with some rewriting of the code,some software cropping of the screen and a new PCB is:

## Proposed System Components

| Component | Choice |
|---|---|
| **SBC** | Raspberry Pi 5 (85×56mm) |
| **Display** | Waveshare 5inch DSI LCD (D) — 720×1280, ILI9881C, 68.04×120.96mm active area |
| **Active area vs OEM** | 68.04mm wide (+1mm), 120.96mm tall (excess hidden by bezel) |
| **CAN bus** | MCP2515 + MCP2561 via SPI (Linux `mcp251x` kernel driver) |
| **3LB bus** | 74LVC245 level shifter → GPIO, read by userspace daemon |
| **Navit D-Bus** | Native on Linux — simpler than Pico approach |
| **Power** | 12V → 5V/3A DC-DC (e.g. Pololu D24V22F5), powers Pi 5 via USB-C |
| **Backlight** | PWM via GPIO → display BL pin, driven by `KO2_Bel_Displ` from K-CAN |

**Animation storage (estimate):** For 50 animations, 4 seconds long at 25 fps, 240x320 (screen cropped to fit the plastic bezel), estimated space:
- 14.65 MB per animation
- 732 MB total (worst case)
- 366 MB total (avg ~50% length)

**Suggested software for animations:** [Synfig](https://www.synfig.org/), [Pixelorama](https://pixelorama.org/)

---

*Platform: VW Passat B6 (3C), 2005–2010, PQ46 platform.
Cluster part numbers: 3C0 920 8xx series.
FIS/MFA screen: 64×88 px monochrome LCD, 1-bit, 3LB protocol.*

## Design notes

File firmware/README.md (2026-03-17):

## Pico FIS Bridge Firmware (VW Passat B6 FIS/MFA)

> WARNING: This firmware is currently **experimental and untested on a real vehicle**. Use at your own risk and validate behaviour on the bench (cluster on the desk, lab supply) before connecting to a car.

PCB files and schematic diagram will be made soon.

Firmware for **Raspberry Pi Pico 2 W** (RP2350) that:

- Listens to Navit navigation events over USB CDC serial from a host (Raspberry Pi, Linux carputer, or Android with Navit).
- Listens to Android head unit media and call events over **Bluetooth SPP** using the onboard CYW43439 via BTstack (no external Bluetooth module).
- Receives the same **serial protocol** (NAV:*, BT:*) on both USB CDC and Bluetooth SPP; fully integrated on both transports.
- Monitors the Passat B6 3LB bus (ENA/CLK/DATA) to detect idle gaps between ECU frames.
- Injects FIS/MFA frames only during idle gaps (no relays or analog switches).

The Pico is a **pure middleman**: the host runs Navit with D-Bus and a bridge script that forwards the protocol to the Pico over USB or Bluetooth.

> **Note:** The OEM radio has been replaced with an Android head unit. The Android head unit does **not** communicate over 3LB. Only the original ECU talks to the FIS/MFA natively over 3LB. The Android head unit communicates with the Pico via Bluetooth SPP.

---

### Bluetooth pairing

The Pico advertises as **`FIS-Bridge`** using classic Bluetooth SPP (BTstack, onboard CYW43439).

Pairing (one time only):
1. Power up the PCB.
2. On the Android head unit, open Bluetooth settings and scan for devices.
3. Select `FIS-Bridge`.
4. Enter PIN **`0000`** if prompted.
5. Pairing is permanent; the head unit reconnects automatically on later power-ups.

The Pico auto-accepts all pairing requests — no user interaction on the Pico side.

---

### Pinout (Pico 2 W)

All 3LB lines must be level-shifted between the 5 V car bus and the Pico's 3.3 V GPIO using BS170 N-channel MOSFETs (TO-92, THT) in the standard NXP bidirectional open-drain level shift circuit, with 2.2 kOhm pull-ups to each rail per channel. Use non-inductive resistors (e.g. metal film or SMD thick/thin film); avoid wirewound types.

**3LB RX (inputs):**

- `GPIO0` – `FIS_PIN_ENA` (ENA, input, bus idle, via level shifter)
- `GPIO1` – `FIS_PIN_CLK` (CLK, input to PIO SM0, via level shifter)
- `GPIO2` – `FIS_PIN_DATA` (DATA, input to PIO SM0, via level shifter)

**3LB TX (outputs):**

- `GPIO3` – `FIS_PIN_ENA_OUT` (ENA, output, claim bus before inject, via level shifter)
- `GPIO4` – `FIS_PIN_CLK_OUT` (CLK, PIO SM1 side-set, via level shifter)
- `GPIO5` – `FIS_PIN_DATA_OUT` (DATA, PIO SM1 out_base, via level shifter)

The TX clock rate is set to **~125 kHz** by default (suspected 3LB bus speed; see main [README section 5.2](../README.md#52-the-3lb-three-line-bus)). To match a different measured speed on your cluster, change `FIS_3LB_TX_CLK_HZ` in `fis_display.c` and rebuild; the main README describes how to measure the CLK line and adjust.

**Optional CAN (firmware has full support; when enabled, MCP2561):** The CAN transceiver is the MCP2561. Two signal connections to the Pico: TXD and RXD. 3.3 V; no level shifter needed. See `fis_can.h` for `FIS_CAN_PIN_*`.

| GPIO | Symbol | Direction | Function |
|---|---|---|---|
| GPIO11 | FIS_CAN_PIN_TX | Out | TX CAN -> MCP2561 TXD |
| GPIO12 | FIS_CAN_PIN_RX | In | RX CAN <- MCP2561 RXD |

MCP2561 TXD connects to Pico GPIO 11; MCP2561 RXD connects to Pico GPIO 12. MCP2561 CANH/CANL to the vehicle Komfort-CAN (Comfort CAN / K-CAN, 100 kbit/s).

**USB:** Pico USB CDC for Navit/host protocol; also 5 V power (VSYS). No 12 V on the PCB.

**Bluetooth:** Onboard CYW43439 via BTstack SPP. Same NAV/BT protocol as USB; no extra GPIO.

---

### Transport (host to Pico)

- **USB CDC** — Host uses `/dev/ttyACM0` (Linux) or equivalent; 115200 baud, newline-terminated.
- **Bluetooth SPP** — Fully integrated. Pico advertises as `FIS-Bridge`, PIN `0000`; host pairs once and sends the same NAV/BT protocol over SPP. BTstack runs alongside USB CDC.

---

### Serial protocol (115200 baud, newline-terminated)

Same on USB CDC and Bluetooth SPP:

| Message | Meaning |
|---|---|
| `NAV:TURN:<code>` | Maneuver type |
| `NAV:DIST:<metres>` | Distance to next turn |
| `NAV:STREET:<name>` | Next street name (max 20 chars) |
| `NAV:STATUS:<status>` | `routing`, `recalculating`, `no_route`, etc. |
| `NAV:ETA:<unix_ts>` | Estimated arrival (Unix ts); converted to local time, shown as e.g. ARR14:32 on clock line 2 |
| `NAV:REMAIN:<metres>` | Remaining distance to destination (Navit `destination_length`); shown on clock line 2 |
| `NAV:HEAD:<degrees>` | Heading 0-360 (Navit `position_direction`); shown as compass (N, NE, E, ...) on clock line 2 |
| `NAV:TIME:<iso8601>` | GPS time UTC (e.g. `2026-03-14T12:34:56Z`), from Navit `position_time_iso8601` |
| `NAV:POS:<lat>,<lon>` | GPS position decimal degrees, from Navit `position_coord_geo` (for timezone lookup) |
| `BT:TRACK:<info>` | Media track info |
| `BT:CALL:<caller>` | Incoming call caller ID |
| `BT:CALLEND` | Call ended |

When `NAV:TIME` and optionally `NAV:POS` are received, the Pico looks up the timezone from a compact bounding-box table stored in flash, computes DST transitions algorithmically (EU rule: last Sunday March/October at 01:00 UTC), converts UTC to local time, and can inject a clock display on the FIS when no nav/media/call is being shown. ETA (Navit `eta`, Unix timestamp) is converted to local time and shown on clock line 2 (e.g. ARR14:32). No network, no OS timezone database, no user configuration.

**Feature toggles:** Send `CFG:<name>:0` or `CFG:<name>:1`. Clock/ETA/compass/remain default to 1 (on). CAN defaults to 0 (off).

| Message | Effect |
|---|---|
| `CFG:CLOCK:0` / `CFG:CLOCK:1` | Show clock (time from GPS); 0 = do not show clock on FIS |
| `CFG:ETA:0` / `CFG:ETA:1` | ETA in local time on clock line 2 (e.g. ARR14:32) |
| `CFG:COMPASS:0` / `CFG:COMPASS:1` | Compass heading on clock line 2 |
| `CFG:REMAIN:0` / `CFG:REMAIN:1` | Remaining distance on clock line 2 |
| `CFG:CAN:0` / `CFG:CAN:1` | CAN bus (full support: send/receive 100 kbit/s, default off). Enable when MCP2561 is fitted on GPIO 11/12. |

---

### CAN bus (full support, disabled by default)

The firmware has **full CAN bus support**: software CAN 2.0A at 100 kbit/s, send and receive standard 11-bit ID frames via MCP2561 on GPIO 11 (TX) and 12 (RX). CAN is **off by default**; the default is in `firmware/fis_config_defaults.h` (`FIS_CAN_ENABLED_DEFAULT 0`). Enable at runtime with `CFG:CAN:1` when MCP2561 hardware is connected.

**Bit rate:** On the VW Passat B6 (PQ46) the bus between the instrument cluster and other modules is the **Komfort-CAN** (Comfort CAN, also K-CAN/KCAN). It runs at **100 kbit/s**, not 500 kbit/s. This is distinct from **Antriebs-CAN** (ACAN, 500 kbit/s; engine, ABS, gearbox) and **Infotainment-CAN** (ICAN, 100 kbit/s; radio, nav, phone). The CAN gateway (J533) bridges between all three. When the Pico/MCP2561 taps in to read or send messages (e.g. mKombi_1, mDiagnose_1), it is on the **Komfort-CAN**.

**Implementation:** Software CAN 2.0A (11-bit ID) at 100 kbit/s: bit timing, CRC-15, and bit stuffing are implemented in `fis_can.c`. Use `fis_can_init()` (or rely on `fis_can_poll` when CAN is enabled), `fis_can_send(const fis_can_frame_t *frame)` to transmit, and `fis_can_receive(fis_can_frame_t *out)` to poll for received frames. Frame structure: `id` (11-bit), `rtr`, `dlc` (0–8), `data[8]`.

**Hardware:**

- **MCP2561** — CAN transceiver; only 2 signal connections to the Pico: **TXD** (GPIO 11) and **RXD** (GPIO 12). Connects to CAN-H/CAN-L on the bus side. Logic side is 3.3 V compatible; **no level shifter** needed (unlike the 3LB side).
- **Termination:** See below; add 120 ohm non-inductive resistor only when your node is at a bus end.
- **Decoupling capacitors** on MCP2561 supply pins.

**CAN termination resistors:**

- **Tapped into the middle of an existing bus** — no termination resistor needed; the two end nodes already provide it.
- **Replacing a node that was a termination endpoint** (e.g. where the OEM radio was) — you may need to add 120 ohm (non-inductive) to replace the termination that was lost when the radio was removed.
- **Standalone bench setup** — both ends need 120 ohm (non-inductive).

To check: measure resistance between CAN-H and CAN-L with everything powered off. You should see approximately **60 ohm** if both terminations are present, or **120 ohm** if only one remains.

---

### Hardware notes

**Level shifters:** 6x BS170 (TO-92, THT), one per 3LB line (3 RX + 3 TX). Two 2.2 kOhm non-inductive pull-ups per channel (3.3 V and 5 V), e.g. metal film or SMD thick/thin film (avoid wirewound). See `BOM.md`.

**3LB connection:** One Molex 3-circuit kit (DigiKey 23-0766500064-ND). Either solder short pigtails to the PCB RX/TX pads and crimp kit housings on the free end (RX: female receptacle 0003061038 + sockets 0002061103; TX: plug 0003062033 + pins 0002062103), or use the kit for wire-to-wire only (plug female into male). See BOM and main README section 5.5.

**Cluster:** Tap 3LB at green T32a — pin 30 DATA, 31 CLK, 32 ENA. Pico RX/TX connect in parallel through level shifters; no relay or analog switch.

---

### Source layout

```text
firmware/
  CMakeLists.txt       – Pico SDK build (Pico 2 W)
  fis_3lb_rx.pio       – PIO SM0: 3LB RX (sniffer)
  fis_3lb_tx.pio       – PIO SM1: 3LB TX (inject)
  fis_rx.h/.c          – Bus idle detection (ENA)
  fis_display.h/.c     – Frame build and inject (nav/media/call/clock)
  serial_parser.h/.c   – USB CDC and Bluetooth SPP line parser (NAV/BT/CFG)
  nav_state.h          – nav_state_t, enums
  fis_config.h/.c           – Feature toggles (clock, ETA, compass, remain, CAN); set via CFG:* serial
  fis_config_defaults.h     – Build-time defaults; CAN disabled by default (FIS_CAN_ENABLED_DEFAULT 0)
  fis_can.h/.c              – Optional CAN bus (default off); software CAN 2.0A at 100 kbit/s, MCP2561 on GPIO 11 (TX) and 12 (RX)
  fis_can_oem.h/.c          – PQ46 OEM messages: mDiagnose_1 (0x7D0, time from GPS), mEinheiten (0x60E, display format), sent every 1 s when CAN enabled
  fis_bridge.c         – main(), dual-core, decision loop
  tz_table.h/.c        – Timezone bounding boxes and DST rules (flash)
  tz_lookup.h/.c       – Timezone lookup by lat/lon, DST and UTC→local
  local_time.h/.c      – Parse ISO8601, format local time and ETA for FIS
  fis_nav_icons.h      – Pre-generated 1-bit nav icon arrays (64x64 px); see nav-icons/README.md and tools/svg_to_fis_icon.py to add icons
```

---

### Build and flash

**Prerequisites (all platforms)**

- Raspberry Pi Pico SDK installed and `PICO_SDK_PATH` set (or SDK at default location).
- CMake 3.13+ and ARM GCC toolchain (`arm-none-eabi-gcc`). See [Raspberry Pi Pico SDK documentation](https://datasheets.raspberrypi.com/pico/raspberry-pi-pico-c-sdk.pdf) for setup.

**Installing the Pico SDK (if missing)**

The SDK is not bundled with this project. Install it as follows.

1. **Clone the SDK** (choose a permanent location, e.g. `$HOME/pico`):

   ```bash
   mkdir -p ~/pico && cd ~/pico
   git clone https://github.com/raspberrypi/pico-sdk.git
   cd pico-sdk
   git submodule update --init
   ```

2. **Set `PICO_SDK_PATH`** so this project can find the SDK. Add to your shell config (e.g. `~/.bashrc` or `~/.zshrc`):

   ```bash
   export PICO_SDK_PATH=$HOME/pico/pico-sdk
   ```

   Then run `source ~/.bashrc` (or `source ~/.zshrc`) or open a new terminal. Alternatively pass the path when configuring: `cmake .. -DPICO_SDK_PATH=$HOME/pico/pico-sdk`.

3. **ARM toolchain (if not installed):**
   - **Linux (Debian/Ubuntu):** `sudo apt install cmake gcc-arm-none-eabi`
   - **Linux (Fedora):** `sudo dnf install cmake arm-none-eabi-gcc-cs`
   - **macOS:** `brew install cmake arm-none-eabi-gcc`
   - **Windows:** Use [MSYS2](https://www.msys2.org/) and `pacman -S mingw-w64-ucrt-x86_64-arm-none-eabi-gcc cmake make`, or the official Pico Windows toolchain.

This repository includes `firmware/pico_sdk_import.cmake`, which uses `PICO_SDK_PATH` to locate the SDK; you do not need to copy any SDK files into this project.

**Build (all platforms)**

From the project root:

```bash
cd firmware
mkdir -p build && cd build
# Set PICO_SDK_PATH to your SDK install (or pass -DPICO_SDK_PATH=... to cmake)
export PICO_SDK_PATH=/path/to/pico-sdk   # e.g. ~/pico/pico-sdk or /opt/pico-sdk
cmake ..
make -j4
```

This produces `pico_fis_bridge.uf2` in `firmware/build/`. Use the same steps for the display-test firmware from `firmware-display-test/` (output: `fis_display_test.uf2`).

---

#### Flashing (UF2 via BOOTSEL) — general

1. Power off the Pico 2 W (unplug USB if it is the only power source).
2. Put the board into BOOTSEL (bootloader) mode:
   - Hold the **BOOTSEL** button on the Pico 2 W.
   - While holding it, connect the USB cable (or apply power via VSYS).
   - Release **BOOTSEL** after the board is connected.
3. The board enumerates as a USB mass storage device. Copy the `.uf2` file onto that volume (see platform steps below).
4. The device resets automatically and runs the new firmware. The mass storage volume disappears and the Pico appears as a USB serial (CDC) port at 115200 baud.

---

#### Windows

**Option A: Build in WSL, flash from Windows**

1. Build the firmware inside WSL (e.g. `cd /mnt/c/Users/YourName/FIS-Display/firmware`, then `mkdir build && cd build`, `cmake ..`, `make`). The UF2 is at `firmware/build/pico_fis_bridge.uf2`.
2. In Windows Explorer, open the project folder (e.g. `C:\Users\YourName\FIS-Display\firmware\build\`).
3. Put the Pico 2 W into BOOTSEL (hold BOOTSEL, plug USB, release). A new removable drive appears (e.g. **RPI-RP2** or a drive letter like **D:** or **E:**).
4. Copy the UF2 file onto the drive:
   - Drag `pico_fis_bridge.uf2` from Explorer and drop it onto the **RPI-RP2** (or the assigned drive) window, or
   - In Command Prompt: `copy pico_fis_bridge.uf2 D:\` (replace `D:` with the actual drive letter; use **This PC** in Explorer to see the correct letter).
5. The Pico resets and runs the new firmware. The drive disappears; use a serial terminal (e.g. PuTTY, 115200 baud) on the new COM port to talk to the firmware.

**Option B: Build natively on Windows**

1. Install [MSYS2](https://www.msys2.org/) or use the official Pico Windows toolchain. Install CMake and `arm-none-eabi-gcc` (e.g. via MSYS2: `pacman -S mingw-w64-ucrt-x86_64-arm-none-eabi-gcc cmake make`). Clone the Pico SDK and set `PICO_SDK_PATH`.
2. In a MSYS2 UCRT64 (or similar) shell: `cd firmware`, `mkdir build`, `cd build`, `cmake .. -G "MinGW Makefiles" -DCMAKE_C_COMPILER=arm-none-eabi-gcc`, `make`. The UF2 is in `build\`.
3. Follow steps 3–5 from Option A: BOOTSEL, then copy `pico_fis_bridge.uf2` onto the **RPI-RP2** drive in Explorer (or via `copy` to the correct drive letter).

**Finding the drive letter:** Open **This PC** (or **File Explorer**). After entering BOOTSEL, a new removable disk **RPI-RP2** appears; note its letter (e.g. **E:**). If it does not appear, try another USB cable/port (data-capable); re-enter BOOTSEL.

---

#### macOS

**Prerequisites**

- Xcode Command Line Tools (for `make`, etc.): `xcode-select --install`
- Homebrew: [brew.sh](https://brew.sh)
- ARM toolchain and CMake: `brew install cmake arm-none-eabi-gcc`
- Pico SDK: clone [pico-sdk](https://github.com/raspberrypi/pico-sdk) and set `PICO_SDK_PATH` to the clone path (e.g. in `~/.zshrc`: `export PICO_SDK_PATH=~/pico/pico-sdk`).

**Build**

```bash
cd firmware
mkdir -p build && cd build
cmake .. -DPICO_SDK_PATH=$PICO_SDK_PATH
make -j4
```

The UF2 is at `firmware/build/pico_fis_bridge.uf2`.

**Flash**

1. Put the Pico 2 W into BOOTSEL: hold **BOOTSEL**, connect USB, then release **BOOTSEL**.
2. A volume named **RPI-RP2** appears on the desktop and in Finder under **Locations**.
3. Copy the UF2 onto the volume:
   ```bash
   cp firmware/build/pico_fis_bridge.uf2 /Volumes/RPI-RP2/
   ```
   Or drag `pico_fis_bridge.uf2` from Finder and drop it onto **RPI-RP2** in the Finder sidebar.
4. The Pico resets; the **RPI-RP2** volume disappears. Connect a serial terminal (e.g. `screen /dev/tty.usbmodem* 115200` or Serial.app) to the new CDC port at 115200 baud.

**If the volume does not appear:** Use a known data-capable USB cable; try another port. Run `system_profiler SPUSBDataType` after plugging in (with BOOTSEL held) to confirm the board is seen as "RPI-RP2" or "RP2 Boot".

---

#### Linux

1. Put the Pico 2 W into BOOTSEL (hold BOOTSEL, plug USB, release). The volume is usually mounted at `/media/$USER/RPI-RP2` (Ubuntu/Debian) or similar; check your file manager or `lsblk` / `dmesg`.
2. Copy the UF2:
   ```bash
   cp firmware/build/pico_fis_bridge.uf2 /media/$USER/RPI-RP2/
   ```
   (Adjust the path if your system mounts it elsewhere.)
3. The device resets and runs the new firmware; the mass storage device disappears.

---

**Alternative: picoprobe / OpenOCD**

If you use a Pico as a probe or another debugger, you can flash the `.elf` or `.uf2` with OpenOCD or `picotool` instead of BOOTSEL. The build output in `build/` includes `pico_fis_bridge.elf` and `pico_fis_bridge.uf2`.

---

### Runtime behaviour

**Core 0:** Initialises USB CDC and BTstack SPP (`FIS-Bridge`, PIN `0000`). Polls both for newline-terminated lines, parses `NAV:*`, `BT:*`, and `CFG:*` messages, updates shared `nav_state_t` and `fis_config_t` under a critical section. When CAN is enabled (`CFG:CAN:1`), calls `fis_can_poll`, which initialises CAN GPIO if needed and drains received frames. Application code can call `fis_can_send()` and `fis_can_receive()` to transmit and receive standard 11-bit ID frames.

**Core 1:** Runs the 3LB loop: monitors ENA for idle, snapshots `nav_state_t` and `fis_config_t`, then injects (in order of priority) call frame, nav frame, media frame, or clock frame (if clock enabled and GPS time available); otherwise leaves bus to the ECU.

**Injection:** Wait for bus idle (ENA high), drive ENA/CLK/DATA via PIO SM1 for the frame, then release.

---

### Display

The FIS/MFA is a 64x88 pixel monochrome LCD. The firmware sends two 3LB frame types (TLBFISLib-compatible):

- **Radio text (0x81):** Two lines of 8-character text for nav, call, media, and clock.
- **Graphics (0x53 + 0x55):** Claim/clear screen then bitmap blocks. Nav icons in `fis_nav_icons.h` (64x64 px, 1-bit) can be sent with `fis_display_inject_icon(index)` or `fis_display_inject_bitmap(x, y, w, h, data)`.

**Prerequisite:** Code the cluster with VCDS or OBDeleven (Module 17 — Instruments) to enable the navigation source.

**Adding custom icons:** Add an SVG in [nav-icons/](../nav-icons/), run `python3 tools/svg_to_fis_icon.py nav-icons/your_icon.svg`, then add the printed C array and `FIS_ICON_TABLE` entry to `fis_nav_icons.h` and increment `FIS_ICON_COUNT`. See [nav-icons/README.md](../nav-icons/README.md).

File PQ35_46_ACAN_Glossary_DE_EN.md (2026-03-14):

# PQ35/46 ACAN K-Matrix – German to English translation table

Glossary for the document **PQ35_46_ACAN_KMatrix_V5.20.6F_20160530_MH.xlsx** (VW/Audi PQ35/46 CAN matrix). Terms are listed in alphabetical order by German term.

| German | English |
|---|---|
| Ablauf | Sequence / expiry |
| Abblendlicht | Low beam |
| Antriebsstrang | Drivetrain |
| Abblendursache | Low-beam cause |
| Abgleich | Matching / calibration |
| Abschaltstufen | Shutdown stages |
| Abweichend | Divergent / differing |
| Aktualisierung | Update |
| Anbindung | Connection / interface |
| Anforderung | Request |
| Angezogen (angez.) | Applied / engaged |
| Anlage | System / unit |
| Anpassung | Adaptation / adjustment |
| Ansteuerung | Actuation / drive |
| Anzeige | Display / indication |
| Anzeigedrehzahl | Display engine speed |
| Anzeigekonzept | Display concept |
| Aufbau | Structure / layout |
| Aufschaltung | Activation / mapping |
| Ausfall | Failure / fault |
| Ausführung | Version / variant |
| Ausschluss | Exclusion |
| Bedienung | Operation / handling |
| Belegung | Assignment / mapping |
| Bemerkung | Remark / note |
| Botschaft | Message (CAN) |
| Botschaftsrouting | Message routing |
| Bremse | Brake |
| Bremskontroll-Lampe | Brake warning lamp |
| Bremsruck | Brake jerk / deceleration |
| Byte | Byte |
| Dämpfer | Damper / shock absorber |
| Darstellung | Display / representation |
| Dauerhaft | Permanent / persistent |
| Diagnose | Diagnosis / diagnostic |
| Drehzahl | Speed (rpm) / rotational speed |
| Durchgeführt | Carried out / performed |
| ECAN | Extended CAN |
| Einbau | Installation |
| Einheit | Unit |
| Einheiten | Units (measurement) |
| Einrichtung | Configuration / setup |
| Einstellung | Setting |
| Empfänger | Receiver |
| Endstellung | End position |
| Entfall | Discontinuation / removal |
| Entfernen | Remove |
| Ergänzung | Addition / supplement |
| Erweiterung | Extension |
| Fahrstufe | Gear / drive range |
| Fahrzeug | Vehicle |
| Fehler | Error / fault |
| Fehlerwert | Error value |
| Fernlicht | High beam |
| Festlegung | Definition / specification |
| Freigabe | Release / enable |
| Funktion | Function |
| Gültig | Valid |
| Gültigkeit | Validity |
| Gang | Gear |
| Gateway | Gateway |
| Getriebe | Transmission / gearbox |
| Heckscheibe | Rear window |
| Hinweis | Note / hint |
| Hochschaltaufforderung | Upshift prompt / recommendation |
| Hochschaltempfehlung | Upshift recommendation |
| Initwert | Initial value |
| Ist-Stand | Current state / as-built |
| Kennung | Identifier / ID |
| Kennungsfolge | Identifier sequence |
| Klemme (Kl.) | Terminal (e.g. Kl.15 = ignition) |
| Kombi | Instrument cluster |
| Kommentar | Comment |
| Kommunikation | Communication |
| Korrektur | Correction |
| Kurbelwelle | Crankshaft |
| Lampe | Lamp / indicator |
| Lastenheft | Specification (document) |
| Lenkrad | Steering wheel |
| Längsbeschleunigung | Longitudinal acceleration |
| Moment | Torque |
| Motor | Engine |
| Nachlauf | Follow-up / run-on |
| Netzwerk | Network |
| Neu | New |
| Neues Signal | New signal |
| Ölwechsel | Oil change |
| Prüfung | Test / check |
| Querbeschleunigung | Lateral acceleration |
| Rückmeldung | Feedback / acknowledgment |
| Rekuperation | Recuperation / regenerative braking |
| Rohsignal | Raw signal |
| Segelbetrieb | Coasting / sailing mode |
| Routing | Routing |
| Sender | Sender / transmitter |
| Signal | Signal |
| Spalte | Column |
| Spannung | Voltage |
| Standzeit | Standing time / park time |
| Starter / Anlasser | Starter motor |
| Steuergerät (SG) | Control unit / ECU |
| Steuerung | Control |
| Stellung | Position / state |
| Stellweg | Actuator travel |
| Stopp | Stop |
| Straße | Street / road |
| Struktur | Structure |
| Temperatur | Temperature |
| Taster | Button / switch |
| Teilnehmer | Participant (node) |
| Überlauf | Overflow |
| Übertragung | Transmission |
| Veraltet | Obsolete / deprecated |
| Verbrauch | Consumption |
| Umfang | Scope / range |
| Umschaltung | Switching |
| Unterdrückung | Suppression |
| Verlustmoment | Loss torque |
| Versorgungsspannung | Supply voltage |
| Verwendung | Use / application |
| Vorhalt | Provision / placeholder |
| Wunschdrehzahl | Requested speed (rpm) |
| Weckursache | Wake-up cause |
| Wert | Value |
| Wiederholung | Repetition |
| Winkel | Angle |
| Zähler | Counter |
| Zeile | Row / line |
| Zündung | Ignition |
| Zyklus | Cycle |
| Zykluszeit | Cycle time |

---

## Abbreviations (German / document-specific)

| Abbreviation | Meaning (DE) | English |
|---|---|---|
| ACAN | Antriebs-CAN | Powertrain CAN |
| ACC | Adaptive Cruise Control | Adaptive Cruise Control |
| BAP | Bedien- und Anzeigeprotokoll | Operating and display protocol |
| BEM | Bordnetz-Energie-Management | On-board power management |
| BCM | Bordnetz-Control-Modul | Body control module |
| BSG | Bordnetz-Steuergerät | On-board power control unit |
| DLC | Data Length Code | Data length (bytes) |
| ECAN | Extended CAN | Extended CAN |
| ECU | Electronic Control Unit | Electronic control unit |
| EKK | Elektrischer Klimakompressor | Electric A/C compressor |
| ESP | Elektronisches Stabilitätsprogramm | Electronic stability program |
| Kl.15 | Klemme 15 | Ignition terminal (ignition on) |
| Kl.30 | Klemme 30 | Battery positive (permanent) |
| Kombi | Kombinationsinstrument | Instrument cluster |
| LWS | Lenkwinkelsensor | Steering angle sensor |
| MSG | Motorsteuergerät | Engine control unit |
| NMH / NM-High | NM-High (diagnostic) | NM-High (diagnostic protocol) |
| PDC | Park-Distance-Control | Park distance control |
| PQ35 / PQ46 | Plattform (VW) | VW platform designation |
| SG | Steuergerät | Control unit |
| StSt / Start-Stopp | Start-Stopp | Start-stop (system) |
| SWA | Spurwechselassistent | Lane change assistant |
| TOG | (display unit) | (display unit) |
| WFS | Wegfahrsperre | Immobilizer |
| ZAS | Zündungs-Anlauf-Steuerung | Ignition/start control |

---

## Document-specific phrases (short)

| German | English |
|---|---|
| Botschaft wird nicht vom Kombi gesendet | Message is not sent by the instrument cluster |
| Falls Senderkennung = 1 (MSG): Bedienung mit Initwert | If sender ID = 1 (MSG): use initial value |
| nicht verbaut | not installed |
| nur für Audi | only for Audi |
| siehe Lastenheft | see specification |
| wg. | because of / due to (wegen) |
| z. Zt. | at present (zur Zeit) |

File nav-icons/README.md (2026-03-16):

# Navigation and status icons (FIS display)

This folder holds SVG sources for the 64x64 pixel 1-bit icons used by the FIS bridge firmware. The firmware uses the converted C arrays from `firmware/fis_nav_icons.h`.

## Icon format (firmware)

- **Size:** 64 x 64 pixels.
- **Bit depth:** 1-bit (black = 1, white = 0).
- **Layout:** Row-major; each row is 8 bytes (64 bits); MSB first (first pixel of row = bit 7 of first byte).
- **Total per icon:** 512 bytes.

## Adding a new icon

### 1. Create or add the SVG

- Place a new SVG in this folder (e.g. `nav_my_icon_bk.svg`). [Inkscape](https://inkscape.org/) is a good tool for creating and editing SVG files.
- The image will be scaled to 64x64; design for that size (simple shapes and strokes work best).
- **No background in the SVG:** use a transparent background (no opaque background rect or fill). The converter renders with a white background; transparent areas become white (0) and black strokes/fills become the icon (1). If the SVG has a dark or opaque background, the whole 64x64 will turn black in the 1-bit output.
- Use black strokes/fill for the icon shape.

### 2. Convert SVG to C array

From the project root, run the converter (requires Python 3 and one of: cairosvg, rsvg-convert, or ImageMagick):

```bash
python3 tools/svg_to_fis_icon.py nav-icons/nav_my_icon_bk.svg
```

To write to a file:

```bash
python3 tools/svg_to_fis_icon.py nav-icons/nav_my_icon_bk.svg -o icon_fragment.c
```

The script prints a C array `ICON_NAV_MY_ICON_BK` and a suggested `FIS_ICON_TABLE` line. If you need a different C symbol:

```bash
python3 tools/svg_to_fis_icon.py nav-icons/nav_my_icon_bk.svg --name MY_CUSTOM_NAME
```

**Dependencies:** For SVG rendering the script tries, in order: `cairosvg` (pip install cairosvg), `rsvg-convert` (librsvg), then ImageMagick `convert`. For 1-bit conversion it needs `Pillow` (pip install Pillow).

### 3. Add the array to the firmware

1. Open `firmware/fis_nav_icons.h`.
2. Paste the generated `static const uint8_t ICON_...[] PROGMEM = { ... };` block **before** the `FIS_ICON_TABLE` definition (e.g. before the "Icon lookup table" comment).
3. Add one entry to `FIS_ICON_TABLE`: use the commented line printed by the script, e.g.  
   `{"nav_my_icon_bk", ICON_NAV_MY_ICON_BK, 64, 64},`  
   Insert it **before** the sentinel `{NULL, NULL, 0, 0}`.
4. Increment `FIS_ICON_COUNT` by 1 (at the bottom of the file).

### 4. Using the new icon

- **By index:** Call `fis_display_inject_icon(index)` with the new icon’s index (same order as in `FIS_ICON_TABLE`; the new icon is at `FIS_ICON_COUNT - 1`).
- **By maneuver (navigation):** If the icon should be shown for a specific Navit maneuver, add a case in `fis_maneuver_to_icon_index()` in `firmware/fis_display.c` that maps the maneuver string to this index.

## Regenerating all icon data

If the icon arrays in `firmware/fis_nav_icons.h` are placeholders (512 bytes of zeros each), the conversion step was never applied. From the project root you can regenerate all arrays from the SVGs in this folder in one go:

```bash
python3 tools/regenerate_nav_icons.py
```

This runs `svg_to_fis_icon.py` for each icon in `FIS_ICON_TABLE` order and rewrites the icon data section of the header. The table and `FIS_ICON_COUNT` are left unchanged.

## Existing icons

The repo ships with 39 icons: navigation maneuvers (left, right, roundabout, exit, merge, etc.), status (routing, recalculating, no_route, etc.), and **nav_eco_mode** for eco mode in the [driver-break plugin](https://github.com/Supermagnum/navit/tree/feature/driver-break/docs/user/plugins/driver-break) (Navit). Their names and order are defined in `FIS_ICON_TABLE` in `firmware/fis_nav_icons.h`.

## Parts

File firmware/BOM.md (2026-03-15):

## Bill of Materials — Pico 2 W FIS Interceptor/Injector PCB (VW Passat B6 FIS)

Firmware target: Raspberry Pi Pico 2 W based inline 3LB (DATA/CLK/ENA) interceptor/injector for the VW Passat B6 (3C) FIS display, with USB CDC to Raspberry Pi (Navit) and Bluetooth SPP to Android head unit. No relays or analog switches; arbitration is done in firmware, with Pico sharing the bus via level shifting.

| Item | Value / Part | DigiKey P/N (example) | Qty | Package | Notes |
|---|---|---|-----|---|---|
| 1 | Raspberry Pi Pico 2 W module (RP2350, WiFi/BT) | `2648-SC0919-ND` (SC0919) | 1 | Module, THT header rows | Main MCU, USB, regulator, WiFi + Bluetooth (used for SPP). Mounts via 2×20 2.54 mm headers. **THT preferred** |
| 2 | BS170 N‑MOSFET (3LB level shift FETs) | `BS170-ND` | 6 | TO‑92 THT | Six channels of level shifting: three RX (GPIO0/1/2 from 5 V bus) and three TX (GPIO3/4/5 to 5 V bus) using NXP bidirectional MOSFET level shifter topology. **THT preferred** |
| 3 | 2.2 kΩ 1/4 W 5 % resistors (5 V pull‑ups for 3LB) | e.g. `CF14JT2K20CT-ND`; mfr **SFR25H0002201FR500** | 6 | Axial THT resistor | 2.2 kΩ from each level‑shifter 5 V side node (ENA/CLK/DATA, RX+TX) to +5 V. Non-inductive. Metal film or SMD thick/thin film; avoid wirewound. **THT preferred** |
| 4 | 2.2 kΩ 1/4 W 5 % resistors (3.3 V pull‑ups for 3LB) | e.g. `CF14JT2K20CT-ND`; mfr **SFR25H0002201FR500** | 6 | Axial THT resistor | 2.2 kΩ from each level‑shifter 3.3 V side node (ENA/CLK/DATA, RX+TX) to +3.3 V. Non-inductive. Metal film or SMD thick/thin film; avoid wirewound. **THT preferred** |
| 5 | 100 Ω 1/4 W 5 % resistor (series with LED) | e.g. `CF14JT100RCT-ND`; mfr **MFP-25BRD52-100R** | 1 | Axial THT resistor | Non-inductive. . Metal film or SMD thick/thin film; avoid wirewound. **THT preferred** |
| 6 | Molex 3‑circuit connector kit (.062" / 1.57 mm) | `23-0766500064-ND` (Mfr **0766500064**) | 1 | KIT CONN STD .062" 3 CIRCUITS | Complete kit for 3LB pigtails and/or wire‑to‑wire. **PCB use:** Solder two short pigtail wires to the PCB RX and TX pads; crimp the kit housings on the free ends: **RX** = female receptacle housing **0003061038** with socket terminals **0002061103**; **TX** = plug housing **0003062033** with pin terminals **0002062103**. Field cables then plug into those pigtails (female into male, male into female); genders prevent swapping RX/TX. **Wire‑to‑wire (no PCB):** Plug the kit female receptacle into the male plug; no soldering, no extra parts. |
| 7 | 3 mm green LED (power indicator) | e.g. `160-1163-ND`; mfr **C503B-GAN-CD0E0781** | 1 | 3 mm THT LED | Indicates board powered from Pi USB (VSYS). Connect with series 100 ohm resistor to 5 V. **THT preferred** |
| 8 | 1×20 2.54 mm female headers (Pico sockets, PCB side), if needed | e.g. `S7039-ND` | 2 | 1×20 THT female header | Sockets for Pico 2 W module, so it is removable/serviceable. **THT preferred** |
| 9 | 1×20 2.54 mm male headers (Pico pins, if needed) | e.g. `S1012EC-20-ND` | 2 | 1×20 THT male header | Soldered to Pico 2 W if not pre‑pinned, to plug into PCB sockets. **THT preferred** |
| 10 | Nylon M3 standoffs (board mounting) | e.g. `RPC2205-ND` | 4 | Nylon standoff | Mechanically mounts board inside dash/enclosure; choose length to suit. |
| 11 | M3 machine screws (board mounting) | e.g. `RPC1495-ND` | 4 | M3 screw | For securing PCB to standoffs or enclosure. |
| 12 | Silkscreen / labeling (no P/N) | – | – | – | Ensure PCB silkscreen clearly labels 3LB RX/TX pad areas (pigtail solder points), ENA/CLK/DATA signal directions, Pico orientation, and indicates Bluetooth device name (“FIS‑Bridge”) for installers. |

**Optional CAN bus:** On the Passat B6 (PQ46) the bus to the cluster is the **Komfort-CAN** (Comfort CAN / K-CAN), 100 kbit/s (not 500 kbit/s). **MCP2561** — CAN transceiver; only 2 signal connections to the Pico: **TXD** (GPIO 11), **RXD** (GPIO 12). Logic side 3.3 V compatible, no level shifter to Pico. **120 ohm** non-inductive termination when your node is at a bus end: mfr **MFR50SFTE52-120R**. (Tapped in the middle: no termination; replacing OEM radio: may need 120 ohm; bench: both ends 120 ohm.) Measure CAN-H to CAN-L with power off: ~60 ohm = both terminations present, ~120 ohm = one. **4700 pF ceramic** cap: mfr **RCER71H472K0M1H03A**. Decoupling capacitors on MCP2561 supply pins. CAN is disabled by default in `firmware/fis_config_defaults.h`. See firmware README for full termination notes.

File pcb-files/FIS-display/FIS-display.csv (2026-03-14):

Reference | Qty | Value | DNP | Exclude from BOM | Exclude from Board | Footprint | Datasheet
A1 | 1 | RaspberryPi_Pico |  |  |  | Module:RaspberryPi_Pico_Common_Unspecified | https://datasheets.raspberrypi.com/pico/pico-datasheet.pdf
C1 | 1 | 4700pf |  |  |  | Capacitor_THT:C_Disc_D3.8mm_W2.6mm_P2.50mm | ~
D1 | 1 | LED |  |  |  | LED_THT:LED_D3.0mm | ~
H1,H2,H3,H4 | 4 | MountingHole_Pad |  | Excluded from BOM |  | MountingHole:MountingHole_3.2mm_M3_DIN965 | ~
J1 | 1 | Conn_01x03_Pin |  |  |  | Connector_JST:JST_PH_B3B-PH-K_1x03_P2.00mm_Vertical | ~
J2 | 1 | Conn_01x03_Socket |  |  |  | Connector_JST:JST_PH_B3B-PH-K_1x03_P2.00mm_Vertical | ~
J3 | 1 | Conn_01x02_Socket |  |  |  | Connector_JST:JST_PH_B2B-PH-K_1x02_P2.00mm_Vertical | ~
Q1,Q2,Q3,Q4,Q5,Q6 | 6 | BS170 |  |  |  | Package_TO_SOT_THT:TO-92_Inline | https://www.onsemi.com/pub/Collateral/BS170-D.PDF
R1 | 1 | 120 ohm |  |  |  | Resistor_THT:R_Axial_DIN0204_L3.6mm_D1.6mm_P5.08mm_Vertical | ~
R2,R3,R4,R5,R6,R7,R8,R9,R10,R11,R12,R13 | 12 | 2.2 kΩ |  |  |  | Resistor_THT:R_Axial_DIN0204_L3.6mm_D1.6mm_P5.08mm_Vertical | ~
R14 | 1 | 100 |  |  |  | Resistor_THT:R_Axial_DIN0204_L3.6mm_D1.6mm_P5.08mm_Vertical | ~
U2 | 1 | MCP2561-H-P |  |  |  | Package_DIP:DIP-8_W7.62mm | http://ww1.microchip.com/downloads/en/DeviceDoc/25167A.pdf

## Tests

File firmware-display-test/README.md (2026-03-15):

# FIS Display Test Firmware

Standalone firmware that **cycles through all display modes** supported by the main FIS bridge every **4 seconds**. Use it to verify that the cluster display works and that every screen type (navigation text, caller ID, audio track, clock) is shown correctly.

No serial input or host is required. Demo content is generated on the Pico.

---

## What it cycles through

Every 4 seconds the display advances to the next phase:

- **Phases 0-4**: Nav text (distance + maneuver + street).
- **Phases 5-37**: All 33 nav/status icons from `fis_nav_icons.h` (bitmap graphics, 64x64 px each).
- **Phase 38**: Call (CALL / Test Caller).
- **Phase 39**: Media (TRACK / Test Track).
- **Phase 40**: Clock (local time + line 2).

After phase 40 it wraps to 0. Full cycle is 41 x 4 = 164 seconds.

---

## Building

Same pinout and hardware as the main firmware (see [firmware/README.md](../firmware/README.md)). Build the same way as the main firmware: set `PICO_SDK_PATH` (e.g. `export PICO_SDK_PATH=$HOME/pico/pico-sdk` or add to `~/.bashrc` and `source` it). This project reuses the SDK import script from `../firmware/pico_sdk_import.cmake`.

```bash
cd firmware-display-test
mkdir -p build
cd build
cmake ..
make -j4
```

Output: `firmware-display-test/build/fis_display_test.uf2`.

If the SDK is not installed, see [firmware/README.md - Installing the Pico SDK](../firmware/README.md#installing-the-pico-sdk-if-missing).

## Flashing

Use the same BOOTSEL procedure as the main firmware; only the UF2 file name differs.

- **Windows:** Put Pico 2 W into BOOTSEL (hold BOOTSEL, plug USB, release). Copy `fis_display_test.uf2` onto the **RPI-RP2** drive in Explorer (or `copy fis_display_test.uf2 D:\` with the correct drive letter). Full steps: [firmware/README.md - Windows](../firmware/README.md#windows).
- **macOS:** Put Pico 2 W into BOOTSEL, then `cp fis_display_test.uf2 /Volumes/RPI-RP2/` or drag the file onto the **RPI-RP2** volume in Finder. Prerequisites and details: [firmware/README.md - macOS](../firmware/README.md#macos).
- **Linux:** `cp fis_display_test.uf2 /media/$USER/RPI-RP2/` (or your mount path) after entering BOOTSEL.

---

## Use case

- **Bench test**: Connect the PCB to a Passat B6 cluster (with correct level shifters and 3LB wiring). Power up; the display should cycle through all modes so you can check segments and contrast.
- **No host**: No USB or Bluetooth host is needed; the Pico runs alone.
- **Same 3LB behaviour**: Uses the same 3LB RX (idle detection) and TX (inject) logic as the main firmware, so you also verify bus timing and coexistence.

The main firmware sends the same frame types (radio text 0x81); this test only replaces the content source with fixed demo data and a 4 s timer.

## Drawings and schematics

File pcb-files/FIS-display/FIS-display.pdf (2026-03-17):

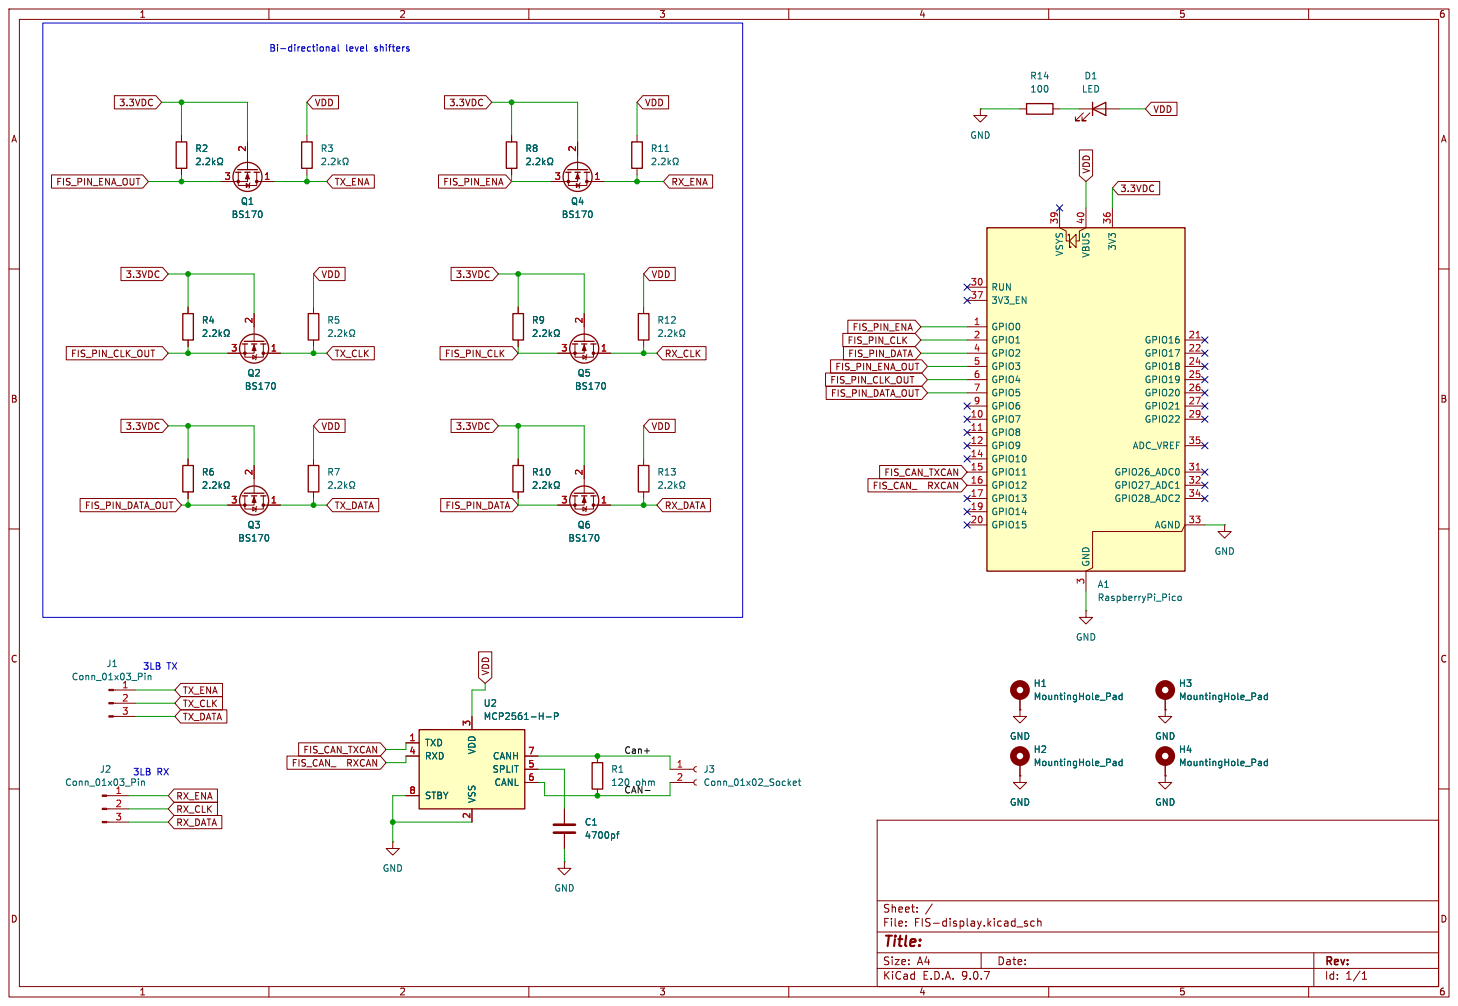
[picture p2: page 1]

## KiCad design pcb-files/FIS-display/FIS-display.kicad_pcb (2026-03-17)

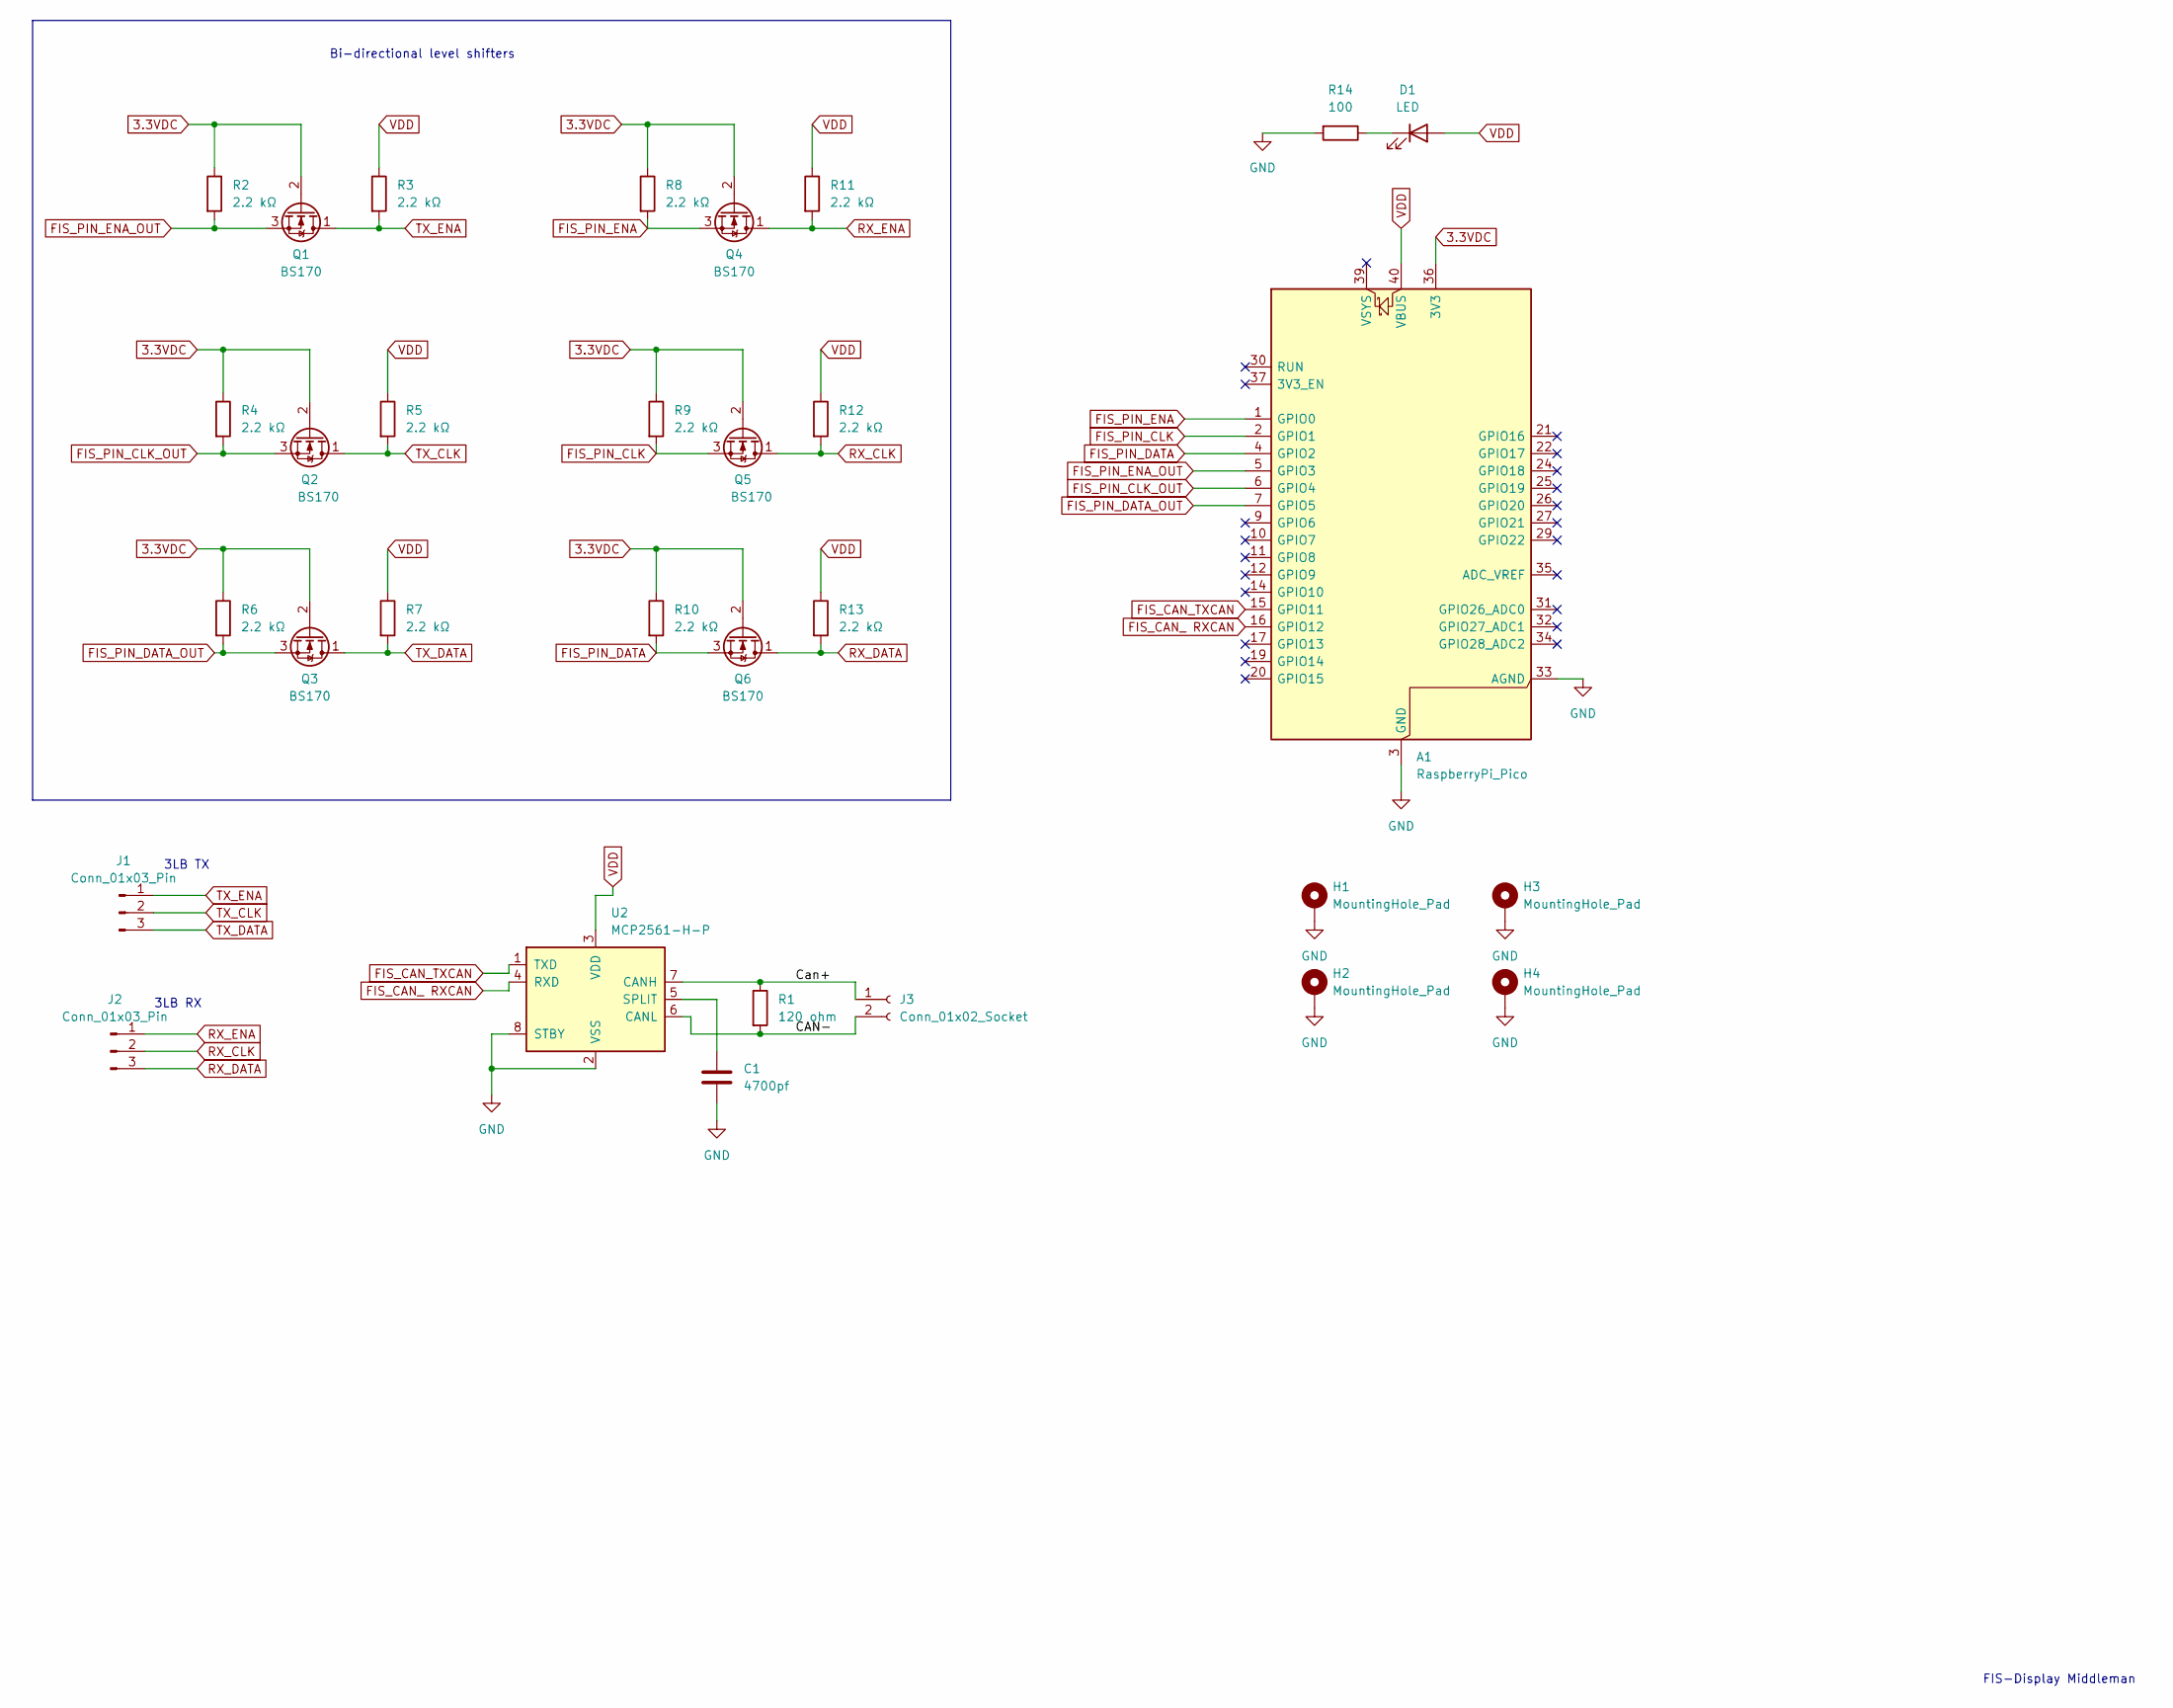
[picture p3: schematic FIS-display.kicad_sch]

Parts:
A1: RaspberryPi_Pico; RaspberryPi_Pico_Common_Unspecified
C1: 4700pf; C_Disc_D3.8mm_W2.6mm_P2.50mm
D1: LED; LED_D3.0mm
H1, H2, H3, H4: MountingHole_Pad; MountingHole_3.2mm_M3_DIN965
J1, J2: Conn_01x03_Pin; PinHeader_1x03_P2.54mm_Vertical
J3: Conn_01x02_Socket; JST_PH_B2B-PH-K_1x02_P2.00mm_Vertical
Q1, Q2, Q3, Q4, Q5, Q6: BS170; TO-92_Inline
R1: 120 ohm; R_Axial_DIN0204_L3.6mm_D1.6mm_P5.08mm_Vertical
R2, R3, R4, R5, R6, R7, R8, R9, R10, R11, R12, R13: 2.2 kΩ; R_Axial_DIN0204_L3.6mm_D1.6mm_P5.08mm_Vertical
R14: 100; R_Axial_DIN0204_L3.6mm_D1.6mm_P5.08mm_Vertical
U2: MCP2561-H-P; DIP-8_W7.62mm

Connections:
3.3VDC: A1.36 (3V3), Q1.2 (G), Q2.2 (G), Q3.2 (G), Q4.2 (G), Q5.2 (G), Q6.2 (G), R2.1, R4.1, R6.1, R8.1, R9.1, R10.1
FIS_CAN_ RXCAN: A1.16 (GPIO12), U2.4 (RXD)
FIS_CAN_TXCAN: A1.15 (GPIO11), U2.1 (TXD)
FIS_PIN_CLK: A1.2 (GPIO1), Q5.3 (S), R9.2
FIS_PIN_CLK_OUT: A1.6 (GPIO4), Q2.3 (S), R4.2
FIS_PIN_DATA: A1.4 (GPIO2), Q6.3 (S), R10.2
FIS_PIN_DATA_OUT: A1.7 (GPIO5), Q3.3 (S), R6.2
FIS_PIN_ENA: A1.1 (GPIO0), Q4.3 (S), R8.2
FIS_PIN_ENA_OUT: A1.5 (GPIO3), Q1.3 (S), R2.2
GND: A1.3 (GND), A1.8 (GND), A1.13 (GND), A1.18 (GND), A1.23 (GND), A1.28 (GND), A1.33 (AGND), A1.38 (GND), C1.2, H1.1, H2.1, H3.1, H4.1, R14.2, U2.2 (VSS), U2.8 (STBY)
unnamed: D1.1 (K), R14.1
unnamed: J3.1, R1.1, U2.7 (CANH)
unnamed: J3.2, R1.2, U2.6 (CANL)
unnamed: C1.1, U2.5 (SPLIT)
RX_CLK: J2.2, Q5.1 (D), R12.2
RX_DATA: J2.3, Q6.1 (D), R13.2
RX_ENA: J2.1, Q4.1 (D), R11.2
TX_CLK: J1.2, Q2.1 (D), R5.2
TX_DATA: J1.3, Q3.1 (D), R7.2
TX_ENA: J1.1, Q1.1 (D), R3.2
VDD: A1.40 (VBUS), D1.2 (A), R3.1, R5.1, R7.1, R11.1, R12.1, R13.1, U2.3 (VDD)

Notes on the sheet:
3LB RX
Bi-directional level shifters
FIS-Display Middleman
3LB TX

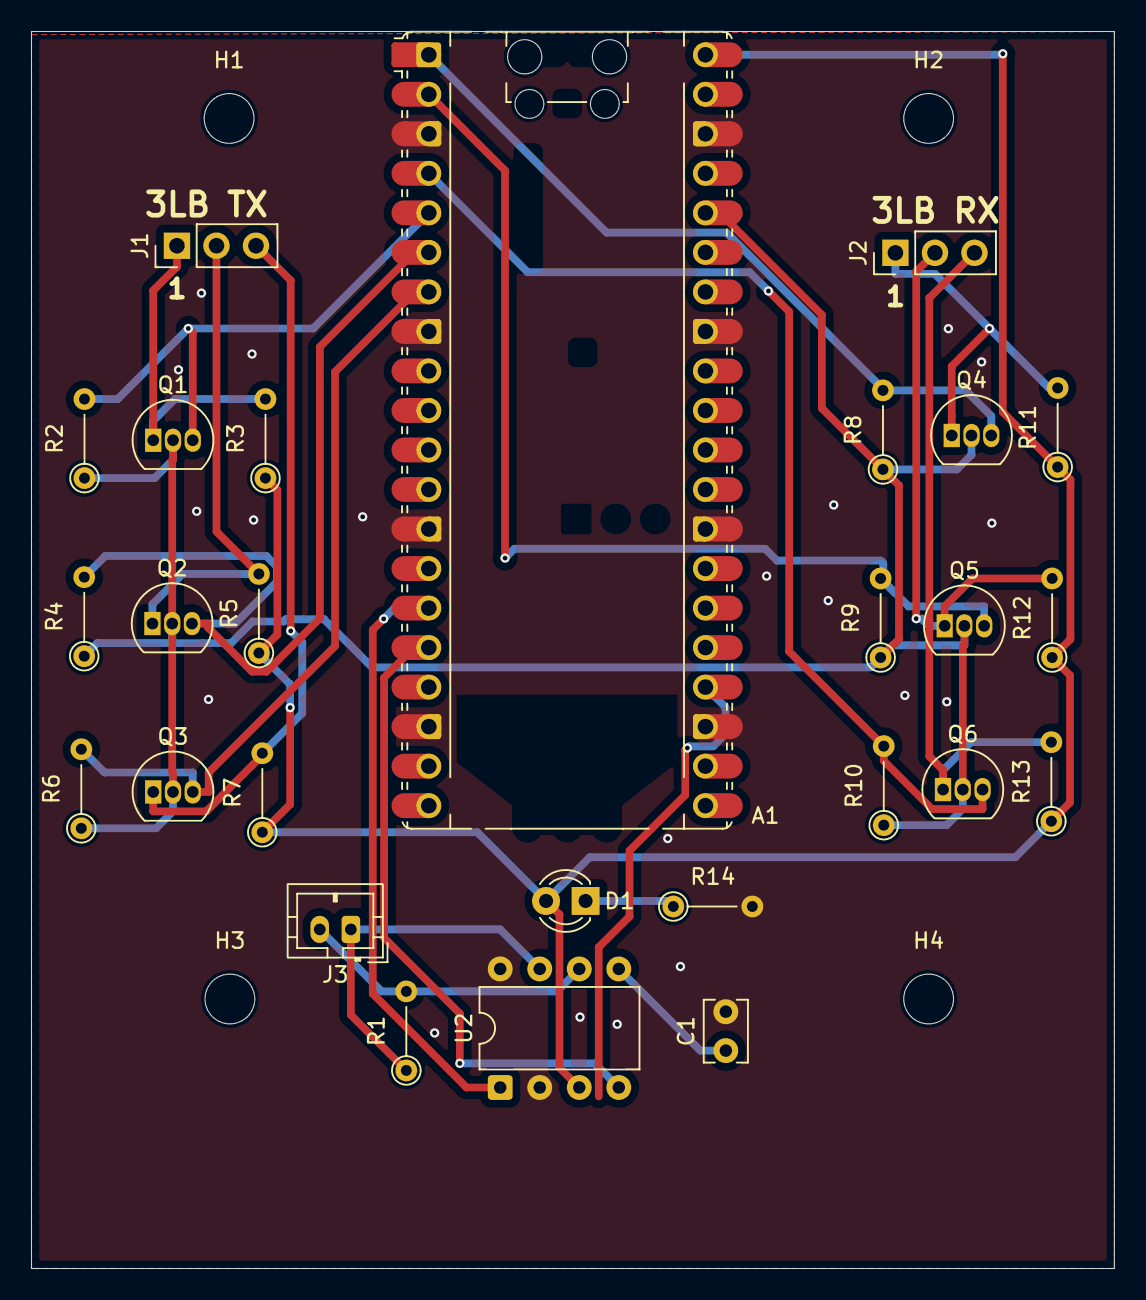
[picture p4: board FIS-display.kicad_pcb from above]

Board: 2 copper layers, 69.6 x 79.5 mm, 31 parts (0 on the bottom side), 21 nets.

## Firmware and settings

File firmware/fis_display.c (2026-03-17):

 #include "fis_display.h"

 #include <ctype.h>
 #include <stdio.h>
 #include <string.h>

 #include "hardware/clocks.h"
 #include "hardware/gpio.h"

 #include "fis_3lb_tx.pio.h"
 #include "fis_nav_icons.h"
 #include "local_time.h"
 #include "tz_lookup.h"

 /* TLBFISLib-style 3LB graphic opcodes and block size */
 #define FIS_3LB_CLEAR_BYTE   0x53u
 #define FIS_3LB_BITMAP_BYTE  0x55u
 #define FIS_3LB_CLAIM_CLEAR  0x82u  /* claim and clear, normal color */
 #define FIS_3LB_BMP_OR       0x02u  /* bitmap OR output (normal) */
 #define FIS_3LB_BLOCK_MAX    42u    /* max bytes per 3LB frame */

 /* Target 3LB CLK frequency (Hz). Suspected ~125-130 kHz; adjust if you measure differently.
  * See main README section 5.2 (3LB bus speed and "Measuring 3LB clock speed and adjusting the firmware"). */
 #define FIS_3LB_TX_CLK_HZ   125000u
 /* PIO cycles per bit in fis_3lb_tx.pio (out + nop side 1 + nop side 0 + jmp) */
 #define FIS_3LB_TX_CYCLES_PER_BIT  6u

 static PIO  s_pio      = pio0;
 static uint s_sm       = 1;
 static uint s_data_pin = FIS_PIN_DATA_OUT;
 static uint s_clk_pin  = FIS_PIN_CLK_OUT;

// Simple helper to send a raw TLBFISLib-style payload as one 3LB frame.
// Bytes are inverted on the wire, matching TLBLib::send_byte().
 static void fis_send_bytes(const uint8_t *data, size_t len) {
     if (!len) {
         return;
     }

     // Assert ENA low for the duration of this frame.
     gpio_put(FIS_PIN_ENA_OUT, 0);

    for (size_t i = 0; i < len; i++) {
        // Wait for space in the FIFO before queuing the next byte.
        while (pio_sm_is_tx_fifo_full(s_pio, s_sm)) {
            tight_loop_contents();
        }
        // TLBLib transfers inverted bytes (0xFF ^ data).
        pio_sm_put(s_pio, s_sm, (uint32_t)(0xFFu ^ data[i]));
    }

     // Wait for transmission to complete.
     while (!fis_display_busy()) {
         tight_loop_contents();
     }

     // Release ENA high, bus back to idle.
     gpio_put(FIS_PIN_ENA_OUT, 1);
 }

 void fis_display_init(PIO pio, uint sm, uint data_pin, uint clk_pin) {
     s_pio      = pio;
     s_sm       = sm;
     s_data_pin = data_pin;
     s_clk_pin  = clk_pin;

     // Configure ENA as output, idle high.
     gpio_init(FIS_PIN_ENA_OUT);
     gpio_set_dir(FIS_PIN_ENA_OUT, GPIO_OUT);
     gpio_put(FIS_PIN_ENA_OUT, 1);

     // Set up CLK pin for side-set and DATA as out_base.
     pio_gpio_init(s_pio, s_data_pin);
     pio_gpio_init(s_pio, s_clk_pin);

     uint offset = pio_add_program(s_pio, &fis_3lb_tx_program);
     pio_sm_config c = fis_3lb_tx_program_get_default_config(offset);

     sm_config_set_out_pins(&c, s_data_pin, 1);
     sm_config_set_sideset_pins(&c, s_clk_pin);

     // Shift right, autopull after 8 bits.
     sm_config_set_out_shift(&c, true, true, 8);

     /* Run TX state machine at FIS_3LB_TX_CLK_HZ so CLK output matches suspected 3LB bus speed. */
     uint32_t sys_hz = clock_get_hz(clk_sys);
     float div = (float)sys_hz / ((float)FIS_3LB_TX_CLK_HZ * (float)FIS_3LB_TX_CYCLES_PER_BIT);
     sm_config_set_clkdiv(&c, div);

     pio_sm_init(s_pio, s_sm, offset, &c);
     pio_sm_set_enabled(s_pio, s_sm, true);
 }

 bool fis_display_busy(void) {
     // Busy while there is data in the TX FIFO or shift register.
     if (!pio_sm_is_tx_fifo_empty(s_pio, s_sm)) {
         return false;
     }
     return (s_pio->fdebug & (1u << (PIO_FDEBUG_TXOVER_LSB + s_sm))) != 0u;
 }

 /* Send claim/clear screen (0x53): fullscreen 64x88, normal color. */
 static void send_claim_screen(void) {
     const uint8_t frame[] = {
         FIS_3LB_CLEAR_BYTE, 5, FIS_3LB_CLAIM_CLEAR,
         0, 0, 64, 88
     };
     fis_send_bytes(frame, sizeof frame);
 }

 /* Send one bitmap block (0x55): option, x, y, then pixel rows. */
 static void send_bitmap_block(uint8_t x, uint8_t y, const uint8_t *pixels,
                               size_t pixel_len) {
     if (pixel_len > FIS_3LB_BLOCK_MAX - 5u) {
         pixel_len = FIS_3LB_BLOCK_MAX - 5u;
     }
     uint8_t frame[FIS_3LB_BLOCK_MAX];
     size_t len = 0;
     frame[len++] = FIS_3LB_BITMAP_BYTE;
     frame[len++] = (uint8_t)(pixel_len + 3u);
     frame[len++] = FIS_3LB_BMP_OR;
     frame[len++] = x;
     frame[len++] = y;
     memcpy(&frame[len], pixels, pixel_len);
     len += pixel_len;
     fis_send_bytes(frame, len);
 }

 /*
 * Inject a 1-bit bitmap at (x,y). Data: row-major, (w+7)/8 bytes per row, MSB first
 * (same layout as fis_nav_icons.h). Sends 0x53 claim then 0x55 bitmap blocks.
 */
void fis_display_inject_bitmap(uint8_t x, uint8_t y, uint8_t w, uint8_t h,
                                const uint8_t *bitmap) {
     if (!bitmap || w == 0 || h == 0) {
         return;
     }
     send_claim_screen();

     const unsigned bytes_per_line = (unsigned)(w + 7u) / 8u;
     const unsigned payload_max   = (unsigned)(FIS_3LB_BLOCK_MAX - 5u);
     const unsigned lines_per_block = payload_max / bytes_per_line;
     if (lines_per_block == 0u) {
         return;
     }

     unsigned row = 0;
     while (row < (unsigned)h) {
         unsigned lines_this = (unsigned)h - row;
         if (lines_this > lines_per_block) {
             lines_this = lines_per_block;
         }
         size_t pixel_bytes = lines_this * bytes_per_line;
         send_bitmap_block((uint8_t)x, (uint8_t)(y + row), bitmap + row * bytes_per_line, pixel_bytes);
         row += lines_this;
     }
 }
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

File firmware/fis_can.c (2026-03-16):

/*
 * Software CAN 2.0A driver for MCP2561 on GPIO 11 (TX) and GPIO 12 (RX).
 * Bit rate: 100 kbit/s (10 us per bit). B6 comfort/infotainment CAN.
 */

#include "fis_can.h"
#include "hardware/gpio.h"
#include "pico/stdlib.h"
#include "pico/time.h"

#include <stdbool.h>
#include <stddef.h>
#include <string.h>

/* 100 kbit/s: 10 us per bit. Sample point ~80% for RX. */
#define FIS_CAN_BIT_US       10u
#define FIS_CAN_SAMPLE_US    8u

/* Max bits after stuffing: SOF(1) + arb(11+1+1+1+4) + data(64) + CRC(15) + delim(1) + ~20 stuff */
#define FIS_CAN_TX_BUF_BITS  128u

static bool s_can_initialized;

/* CRC-15 CAN polynomial: x^15 + x^14 + x^10 + x^8 + x^7 + x^4 + x^3 + 1  =>  0x4599 */
#define FIS_CAN_CRC_POLY  0x4599u

static uint16_t fis_can_crc15_bit(uint16_t crc, bool bit) {
    uint16_t in = (crc << 1) | (bit ? 1u : 0u);
    if (in & 0x8000u)
        in ^= FIS_CAN_CRC_POLY;
    return in & 0x7FFFu;
}

/* Push one unstuffed bit into stream; update crc if non-NULL. *n_bits is count of unstuffed bits so far. */
static void push_bit(unsigned char *buf, unsigned int *n_bits, bool bit, uint16_t *crc) {
    unsigned int byte_ix = *n_bits / 8u;
    unsigned int bit_ix = *n_bits % 8u;
    if (bit)
        buf[byte_ix] |= (unsigned char)(1u << bit_ix);
    else
        buf[byte_ix] &= (unsigned char)~(1u << bit_ix);
    if (crc)
        *crc = fis_can_crc15_bit(*crc, bit);
    (*n_bits)++;
}

/* Append unstuffed bits to buf (LSB first per byte), update crc. *n_bits is total unstuffed. */
static void push_bits(unsigned char *buf, unsigned int *n_bits, uint32_t value, unsigned int num_bits, uint16_t *crc) {
    for (unsigned int i = 0; i < num_bits; i++) {
        push_bit(buf, n_bits, (value >> i) & 1u, crc);
    }
}

/* Build TX bit stream with stuffing. Input: unstuffed bits in buf (num_bits). Output: stuffed into out_buf, return count. */
static unsigned int fis_can_stuff(const unsigned char *buf, unsigned int num_bits, unsigned char *out_buf) {
    unsigned int out_bits = 0;
    unsigned int run = 0;
    bool last = false;
    for (unsigned int i = 0; i < num_bits; i++) {
        unsigned int byte_ix = i / 8u;
        unsigned int bit_ix = i % 8u;
        bool b = (buf[byte_ix] >> bit_ix) & 1u;
        if (b == last) {
            run++;
            if (run == 5) {
                /* Insert stuff bit (opposite). */
                unsigned int ob = out_bits / 8u;
                unsigned int oi = out_bits % 8u;
                out_buf[ob] &= (unsigned char)~(1u << oi);
                out_buf[ob] |= (unsigned char)((!b) ? (1u << oi) : 0u);
                out_bits++;
                run = 0;
                last = !b;
            }
        } else {
            run = 1;
            last = b;
        }
        unsigned int ob = out_bits / 8u;
        unsigned int oi = out_bits % 8u;
        if (b)
            out_buf[ob] |= (unsigned char)(1u << oi);
        else
            out_buf[ob] &= (unsigned char)~(1u << oi);
        out_bits++;
        last = b;
    }
    return out_bits;
}

/* Dominant = low on bus (MCP2561 TXD low); recessive = high. */
static void fis_can_tx_bit(bool dominant) {
    gpio_put(FIS_CAN_PIN_TX, dominant ? 0 : 1);
    busy_wait_us(FIS_CAN_BIT_US);
}

static bool fis_can_rx_bit(void) {
    busy_wait_us(FIS_CAN_SAMPLE_US);
    bool v = gpio_get(FIS_CAN_PIN_RX) != 0;
    busy_wait_us(FIS_CAN_BIT_US - FIS_CAN_SAMPLE_US);
    return v;
}


void fis_can_init(void) {
    if (s_can_initialized)
        return;
    gpio_init(FIS_CAN_PIN_TX);
    gpio_init(FIS_CAN_PIN_RX);
    gpio_set_dir(FIS_CAN_PIN_TX, true);
    gpio_set_dir(FIS_CAN_PIN_RX, false);
    gpio_put(FIS_CAN_PIN_TX, 0);
    s_can_initialized = true;
}

bool fis_can_send(const fis_can_frame_t *frame) {
    if (!frame || frame->dlc > FIS_CAN_MAX_DLC)
        return false;
    if (!s_can_initialized)
        return false;

    unsigned char unstuffed[16];
    memset(unstuffed, 0, sizeof unstuffed);
    unsigned int n_bits = 0;
    uint16_t crc = 0;

    push_bit(unstuffed, &n_bits, false, &crc);  /* SOF dominant */
    push_bits(unstuffed, &n_bits, frame->id & FIS_CAN_STD_ID_MASK, 11, &crc);
    push_bit(unstuffed, &n_bits, frame->rtr, &crc);
    push_bit(unstuffed, &n_bits, false, &crc);  /* IDE = 0 standard */
    push_bit(unstuffed, &n_bits, false, &crc);  /* r0 */
    push_bits(unstuffed, &n_bits, frame->dlc & 0xFu, 4, &crc);
    for (unsigned int i = 0; i < frame->dlc; i++)
        push_bits(unstuffed, &n_bits, frame->data[i], 8, &crc);

    /* CRC and delimiter: append 15-bit CRC (LSB first) then 1 recessive. CRC not included in CRC calc. */
    for (unsigned int i = 0; i < 15u; i++)
        push_bit(unstuffed, &n_bits, (crc >> i) & 1u, NULL);
    push_bit(unstuffed, &n_bits, true, NULL);   /* CRC delimiter recessive */

    unsigned char stuffed[20];
    memset(stuffed, 0, sizeof stuffed);
    unsigned int stuffed_bits = fis_can_stuff(unstuffed, n_bits, stuffed);

    /* Send stuffed frame. */
    for (unsigned int i = 0; i < stuffed_bits; i++) {
        unsigned int ob = i / 8u;
        unsigned int oi = i % 8u;
        bool b = (stuffed[ob] >> oi) & 1u;
        fis_can_tx_bit(!b);  /* b=1 recessive, b=0 dominant; tx_bit(dominant) drives low for dominant */
    }

    /* ACK slot: we send recessive; receiver may drive dominant. */
    fis_can_tx_bit(true);
    /* ACK delimiter + EOF (7 recessive). */
    for (int i = 0; i < 8; i++)
        fis_can_tx_bit(true);

    return true;
}

/* Read one bit with destuffing. Returns false on timeout or error. */
static bool fis_can_rx_bit_destuff(bool *bit_out, unsigned int *run_count, bool *last_bit) {
    bool b = fis_can_rx_bit();
    if (b == *last_bit) {
        (*run_count)++;
        if (*run_count == 5) {
            /* Next bit is stuff bit - skip it. */
            (void)fis_can_rx_bit();
            *run_count = 0;
            *last_bit = !b;
        }
    } else {
        *run_count = 1;
        *last_bit = b;
    }
    *bit_out = b;
    return true;
}

#define FIS_CAN_RX_SOF_TIMEOUT_US  2000u  /* 2 ms; return false if no SOF */

bool fis_can_receive(fis_can_frame_t *out) {
    if (!out || !s_can_initialized)
        return false;

    /* Wait for idle (recessive), then SOF (dominant), with timeout. */
    uint32_t t0 = time_us_32();
    while (gpio_get(FIS_CAN_PIN_RX) == 0) {
        if ((time_us_32() - t0) > FIS_CAN_RX_SOF_TIMEOUT_US)
            return false;
        busy_wait_us(1);
    }
    while (gpio_get(FIS_CAN_PIN_RX) != 0) {
        if ((time_us_32() - t0) > FIS_CAN_RX_SOF_TIMEOUT_US)
            return false;
        busy_wait_us(1);
    }
    /* Now at SOF (dominant). Align to first bit of identifier. */
    busy_wait_us(FIS_CAN_BIT_US);

    unsigned int run = 0;
    bool last = false;
    /* CRC is over SOF through last data bit. We synced on SOF (dominant = 0). */
    uint16_t crc_calc = fis_can_crc15_bit(0, false);
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

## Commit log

2026-03-12 Add Pico 2 W FIS bridge firmware and BOM
    Made-with: Cursor
2026-03-12 Add FIS firmware attribution and BOM fix
    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
2026-03-13 Tweak level shifter resistors and RX reset
    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
    [fis_rx.c]
2026-03-14 Firmware: local time, ETA, compass, remain, feature toggles; docs and OEM CAN reference
    - Timezone from GPS: bbox table in flash, DST algorithm, UTC to local for clock and ETA
    - position_direction (NAV:HEAD) as compass on clock line 2; destination_length (NAV:REMAIN) on clock line 2
    - ETA (NAV:ETA) shown in local time as ARR HH:MM on clock line 2
    - Feature toggles: CFG:CLOCK, CFG:ETA, CFG:COMPASS, CFG:REMAIN (serial); fis_config_t, default all on
    - README: experimental note, PCB note, runtime/clock injection, CFG table, OEM CAN (mDiagnose_1, mEinheiten, mKombi_1/2/3, mGate_Komf_1, mZAS_1, mClima_1, Parkhilfe_01, mSysteminfo_1) reference tables
    - BOM: 2.2k resistor DigiKey P/N corrected to CF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
    [fis_display.c]
2026-03-14 Add project structure, flashing docs, display test, nav icons, glossary
    - README: project structure section with all folders/docs linked (no symlinks)
    - firmware/README: Windows and macOS flashing instructions; Linux flash steps
    - firmware-display-test: standalone display test firmware and README with flash refs
    - firmware: 3LB graphics (0x53/0x55), nav icons, maneuver-to-icon mapping in bridge
    - nav-icons: SVG sources for fis_nav_icons bitmaps
    - PQ35 CAN matrix xlsx and DE-EN glossary
    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
    [PQ35_46_ACAN_KMatrix_V5.20.6F_20160530_MH.xlsx]
2026-03-14 Add toggleable CAN support (default off), config defaults, CAN hardware notes
    - CAN disabled by default in fis_config_defaults.h (FIS_CAN_ENABLED_DEFAULT 0)
    - CFG:CAN:0/1 serial toggle; fis_can stub for future MCP2515+MCP2551
    - Docs: B6 comfort CAN 100 kbit/s, MCP2551-I/P DIP-8, 8 MHz crystal, 22pF, 120 ohm, decoupling; 3.3V logic compatible, no level shifter
    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
2026-03-14 Docs: add optional CAN to system diagram, document CAN/SPI pins (GPIO10-13)
    - System overview diagram: Pico optional branch to MCP2515/MCP2551, comfort CAN 100 kbit/s
    - fis_can.h: define FIS_CAN_PIN_SCK/MOSI/MISO/CS (GPIO10-13) for SPI to MCP2515
    - README and firmware/README: optional CAN pinout table and Pico-MCP2515-MCP2551 wiring
    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
2026-03-14 Docs: CAN termination rules and non-inductive resistors
    - CAN termination: tapped middle (none), replacing radio (may need 120 ohm), bench (both ends); measure CAN-H to CAN-L ~60 ohm / ~120 ohm
    - Specify non-inductive resistors throughout (3LB pull-ups, damping, LED, CAN 120 ohm); metal film or SMD thick/thin film, avoid wirewound
    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
2026-03-14 README: KiCad PCB/schematic note, disclaimer; BOM and firmware updates
    - Note PCB and schematic designed in KiCad; link to pcb-files and Gerber section
    - Disclaimer: creator not responsible for damages, immobile car, injury, etc.
    - BOM: MCP2561, manufacturer P/Ns, qty fixes vs PCB CSV; remove polyfuse, 1k LED R, pushbutton
    - Firmware: CAN default off, MCP2561 GPIO 11/12 (TXD/RXD), config defaults
    - firmware README: CAN pinout, optional CAN description
    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
    [fis_can.c]
2026-03-14 Add datasheets and pcb-files (KiCad project, Gerbers, BOM CSV)
    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
    [FIS-display-B_Cu.gbr, FIS-display-B_Mask.gbr, FIS-display-B_Paste.gbr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]
2026-03-14 README: add Made with KiCad link (kicad.org)
    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
2026-03-14 README: reorganize - disclaimer first, what it does, Gerbers, then technical sections
    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
2026-03-15 Full CAN support, OEM messages, SDK install, display-test build fix
    - firmware: software CAN 2.0A at 100 kbit/s (fis_can.c), GPIO 11/12, MCP2561
    - OEM Komfort-CAN: mDiagnose_1 (0x7D0) and mEinheiten (0x60E) sent every 1 s when CAN enabled
    - local_time_get_local_components() for GPS-to-local time; fis_can_oem_tick() in main loop
    - PIO fix: wait pin,0 syntax in fis_3lb_rx.pio; PIO_FDEBUG_TXOVER_LSB; critical_section.h; tz_lookup stddef.h
    - pico_sdk_import.cmake in firmware/ for SDK discovery; README SDK install instructions
    - README: Komfort-CAN vs ACAN/ICAN, J533 gateway; full CAN support wording
    - BOM numbering 1-17; display-test CMake uses ../firmware/pico_sdk_import, README build steps
    Ma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
    [fis_can.c, fis_display.c]
2026-03-15 BOM: replace PCB connectors with Molex kit; icons: regenerate data, add validation and regen script
    - Remove JST PH PCB headers and housings from BOM; add Molex 0766500064 kit (DigiKey 23-0766500064-ND) for pigtail or wire-to-wire 3LB connection
    - Doc: section 5.5 and firmware README describe RX/TX pigtail wiring (female 0003061038, plug 0003062033) and wire-to-wire use
    - Regenerate all 38 nav icon arrays in fis_nav_icons.h from SVGs; add all-zero check in svg_to_fis_icon.py and regenerate_nav_icons.py; document in nav-icons README and fis_nav_icons.h
    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
    [regenerate_nav_icons.py, svg_to_fis_icon.py]
2026-03-15 PCB: update KiCad design and Gerbers; add design backups
    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
    [FIS-display-B_Cu.gbr, FIS-display-B_Mask.gbr, FIS-display-B_Paste.gbr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]
2026-03-15 BOM: remove optional TVS and debug header; renumber items 1-12; clarify 100R for LED
    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
2026-03-16 Eco mode icon: add SVG, FIS table, mapping; doc driver-break D-Bus and no-override policy
    - Add nav_eco-mode.svg and ICON_NAV_ECO_MODE to fis_nav_icons.h (FIS_ICON_COUNT 39)
    - Map NAV:TURN:eco_mode/eco to icon 38 in fis_display.c (driver-break plugin)
    - README 3.1: when to show eco (D-Bus eco-mode engaged, ECU, energy routing), must NOT override routing; how to add D-Bus attribute/signal and bridge logic (brief display then real maneuver)
    - nav-icons README: 39 icons, nav_eco_mode for driver-break eco mode
    - Key references: link to driver-break plugin docs
    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
2026-03-16 Add navit_dbus_to_pico_bridge.py with eco_mode_fuel_enabled support
    - Host script forwards Navit D-Bus to Pico over serial (USB/Bluetooth)
    - When eco_mode_fuel_enabled is true and route is ready, shows eco icon briefly then real first turn
    - README: document script, run instructions, and tools table entry
    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
2026-03-16 CAN RX parsing, README section 10: MSP3222 pinout and screen upgrade docs
    Firmware:
    - Add fis_can_rx: full K-CAN parsing (mKombi_1/2/3, mGate_Komf_1, mZAS_1, Parkhilfe_01)
    - fis_can_ensure_init(), integrate fis_can_rx_poll in bridge
    - Parsed state: speed, fuel, temp, brightness, ignition, doors, PDC, warnings, standzeit
    README section 10:
    - No firmware support for TFT/icons; use nav-icons for icon sources
    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
2026-03-16 README: add PCB 3D image; update PCB/KiCad and Gerbers
    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
    [FIS-display-B_Cu.gbr, FIS-display-B_Mask.gbr, FIS-display-B_Paste.gbr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]
2026-03-17 README: section 10 formatting, LCD wiki/driver refs, ILI9341 window addressing; PCB/KiCad/PDF/Gerbers
    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
    [FIS-display-B_Cu.gbr, FIS-display-B_Mask.gbr, FIS-display-B_Paste.gbr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]
2026-03-17 3LB TX at ~125 kHz; README bus speed and arbitration; firmware note
    - fis_display.c: PIO clock divider for 3LB TX at FIS_3LB_TX_CLK_HZ (125000);
    add FIS_3LB_TX_CYCLES_PER_BIT, comment references README 5.2
    - README: 3LB speed suspected ~125-130 kHz, doc hard to find; add instructions
    to measure CLK and adjust FIS_3LB_TX_CLK_HZ; fix bus arbitration (pull ENA
    low to claim, wait when ENA low)
    - firmware/README: note on TX clock ~125 kHz and link to main README 5.2
    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
    [fis_display.c]
